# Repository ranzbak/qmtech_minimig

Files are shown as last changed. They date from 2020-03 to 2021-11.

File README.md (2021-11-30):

# Open Adaptive Amiga Retro System (Open AARS)

This PCB has been designed for my project in order to run the Minimig Amiga core on a board of my own design.
The core FPGA board I bought of Aliexpress, because soldering the very fine pitched BGA socket is too cumbersome.

More detailed documents regarding the I/O board can be found in the docs directory in this repository.

The board as is works, the features have been tested individually, but I'm still working on the Minimig port at this time.
Since I work on this in my spare time progress is not super fast, but progress is made.
For now I'm mostly learning and developing at the same time so a lot of stuff changes.
When the code base becomes more stable and usable I'll open the repository up.

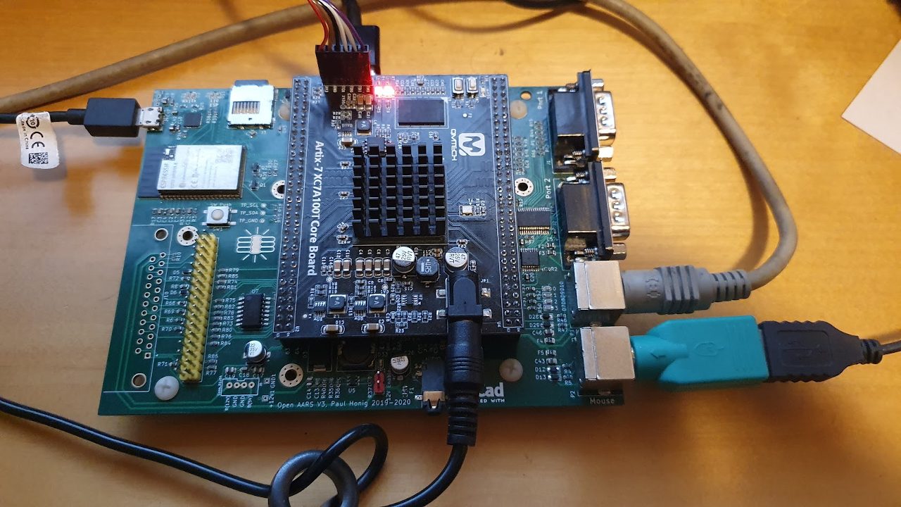
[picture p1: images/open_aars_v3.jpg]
Open AARS V3


[Firmware](https://github.com/ranzbak/MinimigAGA_TC64) for the Amiga works!

## Interfaces provided by this I/O board

- Atari/Amiga compatible Joystick ports
- PS/2 keyboard interface for mouse and keyboard
- Analog head phone jack via
- External floppy interface to connect Amiga floppy drives (Including 12V power pin)
- HDMI display connector that supports up to full HD video (1920x1080)
- 6 status LEDS
- Internal Amiga floppy drive connector
- External Amiga floppy drive connector (DIN-23)
- AS4C16M16SA-6TCN 32Mb SDRAM
- ADV7511 HDMI output PHY
- MAX9850 I2S Audio chip with built in amplifier
- SD-card interface
- RS-232 over USB to program and communicate with the Python shell

## Platforms that _could_ run with this IO board

- C64
- Amiga 1200/500(+) [https://github.com/ranzbak/MinimigAGA_TC64](https://github.com/ranzbak/MinimigAGA_TC64)
- Atari ST
- Other 80's and 90's machines?

Keep in mind I'm only planning on making an Amiga core for this board, but feel free to contribute other cores.

# The two boards that are compatible with this design are

## QM_XC7A100T_DDR3

### Specs

- On-Board FPGA: XC7A100T-2FGG676I;
- On-Board FPGA external crystal frequency: 50MHz;
- XC7A100T-2FGG676I has rich block RAM resource up to 4,860Kb;
- XC7A100T-2FGG676I has 101,440 logic cells;
- On-Board MT25QL128 SPI Flash,16M bytes for user configuration code;
- On-Board 256MB Micron DDR3，MT41K128M16JT-125:K;
- On-Board 3.3V power supply for FPGA by using MP2315 wide input range DC/DC;
- XC7A100T core board has two 64p, 2.54mm pitch headers for extending user IOs. All IOs are precisely designed with length matching;
- XC7A100T core board has 3 user switches;
- XC7A100T core board has 4 user LEDs;
- XC7A100T core board has JTAG interface, by using 6p, 2.54mm pitch header;
- XC7A100T core board PCB size is: 6.7cm x 8.4cm;
- Default power source for board is: 1A@5V DC, the DC header type: DC-050, 5.5mmx2.1mm;

### Github repo

[QM_XC7A100T_STARTER_KIT](https://github.com/ChinaQMTECH/QM_XC7A100T_STARTER_KIT)

### Listings at this time (2019-12-29)

- [Ebay QMTECH Xilinx FPGA Artix7 Artix-7 XC7A100T Core Board](https://www.ebay.com/itm/QMTECH-Xilinx-FPGA-Artix7-Artix-7-XC7A100T-Core-Board-/173922141347)
- [Aliexpress QMTECH Xilinx FPGA Artix7 Artix-7 XC7A100T DDR3 Core Board](vid=bcf629d3-8718-47b9-bad6-a31d7b1e778c&algo_expid=bcf629d3-8718-47b9-bad6-a31d7b1e778c-14&btsid=29203478-817f-4791-b6b6-1687369426ed&ws_ab_test=searchweb0_0,searchweb201602_3,searchweb201603_53)

## QM_XC7A35T_DDR3

### Specs

- On-Board FPGA: XC7A35T-1FTG256C;
- On-Board FPGA external crystal frequency: 50MHz;
- XC7A35T-1FTG256C has rich block RAM resource up to 1,800Kb;
- XC7A35T-1FTG256C has 33,280 logic cells;
- On-Board MT28QL128 SPI Flash, 16M bytes for user configuration code;
- On-Board 256MB Micron DDR3, MT41J128M16JT-125:K;
- On-Board 3.3V power supply for FPGA by using MP2315 wide input range DC/DC;
- XC7A35T development board has two 64p, 2.54mm pitch headers for extending user IOs. All IOs are precisely designed with length matching;
- XC7A35T development board has 2 user switches;
- XC7A35T development board has 3 user LEDs;
- XC7A35T development board has JTAG interface, by using 6p, 2.54mm pitch header;
- XC7A35T development board PCB size is: 6.7cm x 8.4cm;
- Default power source for board is: 1A@5V DC, the DC header type: DC-050, 5.5mmx2.1mm;

### Github repo

[QM_XC7A35T_DDR3](https://github.com/ChinaQMTECH/QM_XC7A35T_DDR3)

### Listings at this time (2019-12-29)

- [Ebay Xilinx FPGA Artix7 Artix-7 Core Board XC7A35T DDR3 256MB](https://www.ebay.com/itm/Xilinx-FPGA-Artix7-Artix-7-Core-Board-XC7A35T-DDR3-256MB/293211934785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)
- [Aliexpress QMTECH Xilinx FPGA Artix7 Artix-7 Core Board XC7A35T DDR3 256MB](https://www.aliexpress.com/item/1000006630084.html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,searchweb201602_3,searchweb201603_53)

** Make sure to ask the seller to ship the board without the female headers soldered on, for the Open AARS board male headers are needed. **

## Disclaimer

THE PROJECT IS PROVIDED "AS IS", WITHOUT WARRANTY OF ANY KIND, EXPRESS OR IMPLIED, INCLUDING BUT NOT LIMITED TO THE WARRANTIES OF MERCHANTABILITY, FITNESS FOR A PARTICULAR PURPOSE AND NONINFRINGEMENT. IN NO EVENT SHALL THE AUTHORS OR COPYRIGHT HOLDERS BE LIABLE FOR ANY CLAIM, DAMAGES OR OTHER LIABILITY, WHETHER IN AN ACTION OF CONTRACT, TORT OR OTHERWISE, ARISING FROM, OUT OF OR IN CONNECTION WITH THE PROJECT OR THE USE OR OTHER DEALINGS IN THE PROJECT.

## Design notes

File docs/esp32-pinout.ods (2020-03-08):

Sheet: Welcome
BADGE.TEAM
 | This spreadsheet contains the pinouts of the badges we support.
 | It is still a work in progress and may contain errors!
 | Version | 1.0.0
 | CHANGELOG
 | 1.0.0 | Initial version

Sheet: ESP32
GPIO | Power group | Bootstrap | Note | SHA2017 | HackerHotel 2019 | CampZone 2019 | Disobey 2019 | Disobey 2020 prototype 1 | Disobey 2020 prototype 2 | Espressif Wrover Kit | Odroid Go | TTGO LoRa | Fri3dcamp 2018 | OpenHardwareSummit 2018 | Troopers 2019 | Open aars
0 | VDD3P3_RTC | LOW=UART DL | Download / run | Flash / button | Flash / button | FLASH (/ PWM?) | Flash / button | Flash / button | Flash / button | Flash / button / LED 2 | Flash / button VOLUME | Flash / button | Flash / button | Flash | Flash | Flash / button
1 | VDD3P3_CPU | UART TX | Serial port TX | UART TX | UART TX | UART TX | UART TX | UART TX | UART TX | UART TX | UART TX | UART TX | UART TX | UART TX | UART TX | UART TX
2 | VDD3P3_RTC | Needs pull down for UART DL mode |  | SDCARD D0 | I2S DATA (OUT) | Not connected ?PWM? | Not connected | I2S1 DATA (OUT) | SDCARD D0 | SDCARD D0 / LED 3 | LED | LED | Display shift-register data | Power enable | SDCARD D0 | SDCARD D0
3 | VDD3P3_CPU | UART RX | Serial port RX | UART RX | UART RX | UART RX | UART RX | UART RX | UART RX | UART RX | UART RX | UART RX | UART RX | UART RX | UART RX | UART RX
4 | VDD3P3_RTC |  |  | EXTIO-3 | Vibration motor | I2C SDA | Not connected | WS2812 DATA | WS2812 DATA | SDCARD D1 / LED 1 | Unconnected / pinheader | I2C SDA | Display shift-register clk | EINK BUSY | I2C SDA | SDCARD D1
5 | VDD3P3_CPU |  |  | EINK MOSI | EINK MOSI | I2C CLK | Not connected | IR RX | IR TX | LCD backlight | LCD CS | LoRa SCK | SDCARD CS | EINK CS | I2C CLK
6 | VDD_SDIO |  | Not available | Internal flash CLK | Internal flash CLK | Internal flash CLK | Internal flash CLK | Internal flash CLK | Internal flash CLK | Internal flash CLK | Internal flash CLK | Internal flash CLK | Internal flash CLK | Internal flash CLK | Internal flash CLK | Internal flash CLK
7 | VDD_SDIO |  | Not available | Internal flash DO | Internal flash DO | Internal flash DO | Internal flash DO | Internal flash DO | Internal flash DO | Internal flash DO | Internal flash DO | Internal flash DO | Internal flash DO | Internal flash DO | Internal flash DO | Internal flash DO
8 | VDD_SDIO |  | Not available | Internal flash DI | Internal flash DI | Internal flash DI | Internal flash DI | Internal flash DI | Internal flash DI | Internal flash DI | Internal flash DI | Internal flash DI | Internal flash DI | Internal flash DI | Internal flash DI | Internal flash DI
9 | VDD_SDIO |  | Not available | Internal flash HOLD# | Internal flash HOLD# | Internal flash HOLD# | Internal flash HOLD# | Internal flash HOLD# | Internal flash HOLD# | Internal flash HOLD# | Internal flash HOLD# | Internal flash HOLD# | Internal flash HOLD# | Internal flash HOLD# | Internal flash HOLD# | Internal flash HOLD#
10 | VDD_SDIO |  | Not available | Internal flash WP# | Internal flash WP# | Internal flash WP# | Internal flash WP# | Internal flash WP# | Internal flash WP# | Internal flash WP# | Internal flash WP# | Internal flash WP# | Internal flash WP# | Internal flash WP# | Internal flash WP# | Internal flash WP#
11 | VDD_SDIO |  | Not available | Internal flash CS | Internal flash CS | Internal flash CS | Internal flash CS | Internal flash CS | Internal flash CS | Internal flash CS | Internal flash CS | Internal flash CS | Internal flash CS | Internal flash CS | Internal flash CS | Internal flash CS
12 | VDD3P3_RTC | VDD_SDIO LOW=3.3V HIGH=1.8V | MTDI | EXTIO-4 | IR RX | Not connected (10k to GND) | EXTIO-1 | Buzzer | Buzzer | SDCARD D2 / MTDI | Unconnected / pinheader | Unconnected / pinheader | UART 1 TX | T5 | Not connected | SDCARD D2
13 | VDD3P3_RTC |  |  | SDCARD D3 | I2S CLK | HUB75 R0 | Not connected | I2S1 CLK | I2S1 CLK | SDCARD D3 / MTCK | Button MENU | Unconnected / pinheader | Display shift-register OE | T4 | EINK BUSY | SDCARD D3
14 | VDD3P3_RTC |  |  | SDCARD CLK | IR TX | HUB75 B0 | EXTIO-0 | IR TX | SDCARD CLK | SDCARD CLK / MTMS | LCD backlight | LoRa RESET | UART 2 RX | T6 | SDCARD CLK | SDCARD CLK
15 | VDD3P3_RTC | LOW=BL SILENT, HIGH=BL DEBUG | MTDO | SDCARD CMD | I2S L/R | HUB75 G0 | Not connected | I2S1 L/R | SDCARD CMD | SDCARD CMD / MTDO | Unconnected / pinheader | I2C CLK | Display shift-register latch | SDCARD CS | SDCARD CMD | SDCARD CMD
16 | VDD_SDIO |  |  | EXTIO-1 | Internal SRAM CS | HUB75 A | Not connected | Internal SRAM CS | Internal SRAM CS | Internal SRAM CS | Internal SRAM CS | Display reset | UART 2 RX | EINK RESET | Internal SRAM CS | Internal SRAM CS
17 | VDD_SDIO |  |  | EXTIO-2 | Internal SRAM CLK | HUB75 B | Not connected | Internal SRAM CLK | Internal SRAM CLK | Internal SRAM CLK | Internal SRAM CLK | Unconnected / pinheader | UART 2 TX | Not connected | Internal SRAM CLK | Internal SRAM CLK
18 | VDD3P3_CPU |  |  | EINK SCK | EINK SCK | HUB75 C | IR RX | IR RX PWR | I2S1 DATA (OUT) | LCD RESET | LCD CLK | LoRa CS | SDCARD CLK | EINK SCK | EINK SCK | VSPI_FPGA_CLK
19 | VDD3P3_CPU |  |  | EINK CS | EINK CS | HUB75 LAT | IR TX | I2C interrupt (MPR121) | Not connected | LCD CLK | LCD MISO | LoRa MOSI | SDCARD DO | MISO | LED | VSPI_FPGA_MISO
21 | VDD3P3_CPU |  |  | EINK D/C | EINK D/C | HUB75 CLK | IR RX PWR | SSD1306 RESET | I2S1 L/R | LCD D/C | LCD D/C | Unconnected / pinheader | I2C SDA | I2C SDA | I2C interrupt (Accelerometer) | LED0
22 | VDD3P3_CPU |  |  | EINK BUSY | EINK BUSY | HUB75 OE | I2C SCL | I2C SCL | I2C SCL | LCD CS | SDCARD CS | Unconnected / pinheader | I2C CLK | I2C CLK | WS2812 DATA | LED1
23 | VDD3P3_CPU |  |  | EINK RESET | EINK RESET | CHARGE ENABLE | I2C SDA | I2C SDA | I2C SDA | LCD MOSI | LCD MOSI | Unconnected / pinheader | SDCARD DI | EINK MOSI | EINK MOSI | VSPI_FPGA_MOSI
25 | VDD3P3_RTC |  | DAC1 | I2C interrupt (MPR121) | I2C interrupt (MPR121) | Not connected | I2C interrupt (SAMD) | I2S0 CLK | I2S0 CLK | LCD MISO | DAC (check schematic!) | Unconnected / pinheader | PWM 1 | EINK D/C | EINK CS | FPGA_INT
26 | VDD3P3_RTC |  | DAC2 | I2C SDA | I2C SDA | Button up | EXTIO-2 | EXTIO-0 | EXTIO-0 | Unconnected / pinheader | DAC (check schematic!) | LoRa interrupt | PWM 2 | “LED_BAR_DOUT” but seems NC | Grove signal pin 1 | ADV_I2C SDA
27 | VDD3P3_RTC |  |  | I2C SCL | I2C SCL | Button down | EXTIO-3 | EXTIO-1 | EXTIO-1 | Unconnected / pinheader | Button SELECT | LoRa MOSI | PWM 3 | T7 | EINK D/C | ADV_I2C SCL
32 | VDD3P3_RTC |  |  | WS2812 DATA | WS2812 DATA | Button left | Not connected | Badge type detection | Badge type detection | 32kHz crystal P | Button A | Unconnected / pinheader | h | T9 | 32kHz crystal P | SDCARD power EN (active low)
33 | VDD3P3_RTC |  |  | EXTIO-0 | Not connected | Button right | Not connected | VUSB SENS | IR RX | 32kHz crystal N | Button B | Unconnected / pinheader | Buzzer | T8 | 32kHz crystal N | VSPI_FPGA_CS
34 | VDD3P3_RTC |  | Input only | VUSB SENS | VUSB SENS | VUSB SENS | Not connected | VBAT SENS | I2C interrupt (MPR121) | Unconnected / pinheader | JOY LEFT/RIGHT (analog) | Unconnected / pinheader | I2C interrupt (Accelerometer 1) | I2C interrupt (Accelerometer) | I2C interrupt (PCA9555 / Key 1) | SD_CARD_SW
35 | VDD3P3_RTC |  | Input only | VBAT SENS | VBAT SENS | VBAT SENS | Not connected | I2S0 DATA (IN) | I2S0 DATA (IN) | Unconnected / pinheader | JOY UP/DOWN (analog) | Unconnected / pinheader | I2C interrupt (Accelerometer 2) | VBAT SENS | I2C interrupt (PCA9555 / Key 0) | ADV_INT
36 | VDD3P3_RTC |  | Input only (VP) | Not connected | Not connected | Button A | Not connected | Not connected | VUSB SENS | Unconnected / pinheader | VBAT SENS | Unconnected / pinheader | Button 0 | Not connected | Grove signal pin 0 | Free (Wakeup source, input only)
39 | VDD3P3_RTC |  | Input only (VN) | Not connected | Not connected | Button B | Not connected | Not connected | VBAT SENS | Unconnected / pinheader | Button START | Unconnected / pinheader | Button 1 | Not connected | I2C interrupt (PCA9539A / Button) | Free (Wakeup source, input only)
Note | This row contains notes about each design |  |  | SDCARD D3 seems useless | Audio output is wired wrong | I2C pull-ups have wrong | SAMD handles most I/O | Prototype, do NOT copy | Prototype, do NOT copy | Development board | SD card shares EINK SPI (See notes!) | LoRa radio is not yet | SD card can only be used in SPI mode | SD card shares EINK SPI (See notes!) | Not yet supported by badge.team
 |  |  |  |  | needs software workaround | value, please swap if you |  | (Contains mistakes!) |  | (Some features share pins!) | (Shitty design, do not copy!) | supported |  | Touch buttons are not yet supported | firmware
 |  |  |  |  |  | plan on using I2C
 |  | Design hints
 |  | - If you want to be able to wake-up the ESP32 from deep-sleep using a pin make sure that the pin you use is in the VDD3P3_RTC power domain (Disobey 2020 prototype 1 got this wrong…)
 |  | - The SPI bus used by the internal flash can only be used for the internal flash
 |  | - Make sure you strap the bootstrap pins correctly! If you want to you can burn an e-fuse to fix the voltage set by GPIO 12. We had to do this for the hackerhotel 2019 badge
 |  | - The SPI/SD bus used by an SD card can not be shared with other devices, this is a (software) limitation of the ESP-IDF SDK which we do not (yet) have a workaround for
 |  | - To use the SD card in SD mode make sure that you use the right pins to do so, you need the exact pins used on the SHA2017 badge to utilize the SDIO hardware of the ESP32. We wired it up in 1-wire mode, you can also do 4-wire mode for more speed if needed.

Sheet: MPR121
ELE | SHA2017 | HackerHotel 2019 | Disobey 2020 prototype 1
0 | Touch button A | Touch button SELECT | Touch button UP
1 | Touch button B | Touch button START | Touch button DOWN
2 | Touch button START | Touch button A | Touch button LEFT
3 | Touch button SELECT | Touch button UP / RIGHT | Touch button RIGHT
4 | Touch button DOWN | Touch button LEFT / UP | Touch button A
5 | Touch button RIGHT | Touch button DOWN / LEFT | Touch button B
6 | Touch button UP | Touch button RIGHT / DOWN | Touch button SELECT
7 | Touch button LEFT | Touch button B | Touch button START
8 | Vibration motor | Not connected | LED 1
9 | Charging status | Charging status | LED 2
10 | WS2812 / SD power enable | WS2812 power enable | WS2812 power enable
11 | SD card detect | Not connected | SSD1306 power disable
Note | Sd card detect does not |  | Interrupt not wired to pin
 | work |  | capable of deepsleep wakeup
 | COLORS
 | Touch input
 | Digital input
 | Digital output
 | PWM output
 | Not connected

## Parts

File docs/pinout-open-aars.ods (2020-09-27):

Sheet: Sheet1
U71 | GND | Power input | Line | Right | 1,270 mm | 1,270 mm | 5,080 mm | -103,810 mm | 38,176 mm
U72 | GND | Power input | Line | Left | 1,270 mm | 1,270 mm | 5,080 mm | -62,840 mm | 38,176 mm
U73 | 3V3 | Power output | Line | Right | 1,270 mm | 1,270 mm | 5,080 mm | -103,810 mm | 35,636 mm | Space | 2540
U74 | 3V3 | Power output | Line | Left | 1,270 mm | 1,270 mm | 5,080 mm | -62,840 mm | 35,636 mm
U75 | GND | Power input | Line | Right | 1,270 mm | 1,270 mm | 5,080 mm | -103,810 mm | 33,096 mm
U76 | GND | Power input | Line | Left | 1,270 mm | 1,270 mm | 5,080 mm | -62,840 mm | 33,096 mm
U77 | BANK14_M12 | Unspecified | Line | Right | 1,270 mm | 1,270 mm | 5,080 mm | -103,810 mm | 30,556 mm
U78 | BANK14_N13 | Unspecified | Line | Left | 1,270 mm | 1,270 mm | 5,080 mm | -62,840 mm | 30,556 mm
U79 | BANK14_M14 | Unspecified | Line | Right | 1,270 mm | 1,270 mm | 5,080 mm | -103,810 mm | 28,016 mm
U710 | BANK14_N16 | Unspecified | Line | Left | 1,270 mm | 1,270 mm | 5,080 mm | -62,840 mm | 28,016 mm
U711 | BANK14_P15 | Unspecified | Line | Right | 1,270 mm | 1,270 mm | 5,080 mm | -103,810 mm | 25,476 mm
U712 | BANK14_P16 | Unspecified | Line | Left | 1,270 mm | 1,270 mm | 5,080 mm | -62,840 mm | 25,476 mm
U713 | BANK14_R15 | Unspecified | Line | Right | 1,270 mm | 1,270 mm | 5,080 mm | -103,810 mm | 22,936 mm
U714 | BANK14_R16 | Unspecified | Line | Left | 1,270 mm | 1,270 mm | 5,080 mm | -62,840 mm | 22,936 mm
U715 | BANK14_T14 | Unspecified | Line | Right | 1,270 mm | 1,270 mm | 5,080 mm | -103,810 mm | 20,396 mm
U716 | BANK14_T15 | Unspecified | Line | Left | 1,270 mm | 1,270 mm | 5,080 mm | -62,840 mm | 20,396 mm
U717 | BANK14_P13 | Unspecified | Line | Right | 1,270 mm | 1,270 mm | 5,080 mm | -103,810 mm | 17,856 mm
U718 | BANK14_P14 | Unspecified | Line | Left | 1,270 mm | 1,270 mm | 5,080 mm | -62,840 mm | 17,856 mm
U719 | BANK14_T13 | Unspecified | Line | Right | 1,270 mm | 1,270 mm | 5,080 mm | -103,810 mm | 15,316 mm
U720 | BANK14_R13 | Unspecified | Line | Left | 1,270 mm | 1,270 mm | 5,080 mm | -62,840 mm | 15,316 mm
U721 | BANK14_T12 | Unspecified | Line | Right | 1,270 mm | 1,270 mm | 5,080 mm | -103,810 mm | 12,776 mm
U722 | BANK14_R12 | Unspecified | Line | Left | 1,270 mm | 1,270 mm | 5,080 mm | -62,840 mm | 12,776 mm
U723 | BANK14_L13 | Unspecified | Line | Right | 1,270 mm | 1,270 mm | 5,080 mm | -103,810 mm | 10,236 mm
U724 | BANK14_N12 | Unspecified | Line | Left | 1,270 mm | 1,270 mm | 5,080 mm | -62,840 mm | 10,236 mm
U725 | BANK14_K12 | Unspecified | Line | Right | 1,270 mm | 1,270 mm | 5,080 mm | -103,810 mm | 7,696 mm
U726 | BANK14_K13 | Unspecified | Line | Left | 1,270 mm | 1,270 mm | 5,080 mm | -62,840 mm | 7,696 mm
U727 | BANK14_P10 | Unspecified | Line | Right | 1,270 mm | 1,270 mm | 5,080 mm | -103,810 mm | 5,156 mm
U728 | BANK14_P11 | Unspecified | Line | Left | 1,270 mm | 1,270 mm | 5,080 mm | -62,840 mm | 5,156 mm
U729 | BANK14_N9 | Unspecified | Line | Right | 1,270 mm | 1,270 mm | 5,080 mm | -103,810 mm | 2,616 mm
U730 | BANK14_P9 | Unspecified | Line | Left | 1,270 mm | 1,270 mm | 5,080 mm | -62,840 mm | 2,616 mm
U731 | BANK14_T10 | Unspecified | Line | Right | 1,270 mm | 1,270 mm | 5,080 mm | -103,810 mm | 0,076 mm
U732 | BANK14_R11 | Unspecified | Line | Left | 1,270 mm | 1,270 mm | 5,080 mm | -62,840 mm | 0,076 mm
U733 | BANK14_T9 | Unspecified | Line | Right | 1,270 mm | 1,270 mm | 5,080 mm | -103,810 mm | -2,464 mm
U734 | BANK14_R10 | Unspecified | Line | Left | 1,270 mm | 1,270 mm | 5,080 mm | -62,840 mm | -2,464 mm
U735 | BANK14_T8 | Unspecified | Line | Right | 1,270 mm | 1,270 mm | 5,080 mm | -103,810 mm | -5,004 mm
U736 | BANK14_R8 | Unspecified | Line | Left | 1,270 mm | 1,270 mm | 5,080 mm | -62,840 mm | -5,004 mm
U737 | BANK14_T7 | Unspecified | Line | Right | 1,270 mm | 1,270 mm | 5,080 mm | -103,810 mm | -7,544 mm
U738 | BANK14_R7 | Unspecified | Line | Left | 1,270 mm | 1,270 mm | 5,080 mm | -62,840 mm | -7,544 mm
U739 | BANK14_T5 | Unspecified | Line | Right | 1,270 mm | 1,270 mm | 5,080 mm | -103,810 mm | -10,084 mm
U740 | BANK14_R6 | Unspecified | Line | Left | 1,270 mm | 1,270 mm | 5,080 mm | -62,840 mm | -10,084 mm
U741 | BANK14_P6 | Unspecified | Line | Right | 1,270 mm | 1,270 mm | 5,080 mm | -103,810 mm | -12,624 mm
U742 | BANK14_R5 | Unspecified | Line | Left | 1,270 mm | 1,270 mm | 5,080 mm | -62,840 mm | -12,624 mm
U743 | BANK14_N6 | Unspecified | Line | Right | 1,270 mm | 1,270 mm | 5,080 mm | -103,810 mm | -15,164 mm
U744 | BANK14_M6 | Unspecified | Line | Left | 1,270 mm | 1,270 mm | 5,080 mm | -62,840 mm | -15,164 mm
U745 | BANK34_L5 | Unspecified | Line | Right | 1,270 mm | 1,270 mm | 5,080 mm | -103,810 mm | -17,704 mm
U746 | BANK34_P5 | Unspecified | Line | Left | 1,270 mm | 1,270 mm | 5,080 mm | -62,840 mm | -17,704 mm
U747 | BANK34_T4 | Unspecified | Line | Right | 1,270 mm | 1,270 mm | 5,080 mm | -103,810 mm | -20,244 mm
U748 | BANK34_T3 | Unspecified | Line | Left | 1,270 mm | 1,270 mm | 5,080 mm | -62,840 mm | -20,244 mm
U749 | BANK34_R3 | Unspecified | Line | Right | 1,270 mm | 1,270 mm | 5,080 mm | -103,810 mm | -22,784 mm
U750 | BANK34_T2 | Unspecified | Line | Left | 1,270 mm | 1,270 mm | 5,080 mm | -62,840 mm | -22,784 mm
U751 | BANK34_R2 | Unspecified | Line | Right | 1,270 mm | 1,270 mm | 5,080 mm | -103,810 mm | -25,324 mm
U752 | BANK34_R1 | Unspecified | Line | Left | 1,270 mm | 1,270 mm | 5,080 mm | -62,840 mm | -25,324 mm
U753 | BANK34_M5 | Unspecified | Line | Right | 1,270 mm | 1,270 mm | 5,080 mm | -103,810 mm | -27,864 mm
U754 | BANK34_N4 | Unspecified | Line | Left | 1,270 mm | 1,270 mm | 5,080 mm | -62,840 mm | -27,864 mm
U755 | BANK34_P4 | Unspecified | Line | Right | 1,270 mm | 1,270 mm | 5,080 mm | -103,810 mm | -30,404 mm
U756 | BANK34_P3 | Unspecified | Line | Left | 1,270 mm | 1,270 mm | 5,080 mm | -62,840 mm | -30,404 mm
U757 | BANK34_N1 | Unspecified | Line | Right | 1,270 mm | 1,270 mm | 5,080 mm | -103,810 mm | -32,944 mm
U758 | BANK34_P1 | Unspecified | Line | Left | 1,270 mm | 1,270 mm | 5,080 mm | -62,840 mm | -32,944 mm
U759 | BANK34_M2 | Power input | Line | Right | 1,270 mm | 1,270 mm | 5,080 mm | -103,810 mm | -35,484 mm
U760 | BANK34_M1 | Power input | Line | Left | 1,270 mm | 1,270 mm | 5,080 mm | -62,840 mm | -35,484 mm
U761 | 3V3 | Power output | Line | Right | 1,270 mm | 1,270 mm | 5,080 mm | -103,810 mm | -38,024 mm
U762 | 3V3 | Power output | Line | Left | 1,270 mm | 1,270 mm | 5,080 mm | -62,840 mm | -38,024 mm
U763 | VIN | Power output | Line | Right | 1,270 mm | 1,270 mm | 5,080 mm | -103,810 mm | -40,564 mm
U764 | VIN | Power output | Line | Left | 1,270 mm | 1,270 mm | 5,080 mm | -62,840 mm | -40,564 mm
U81 | GND | Power input | Line | Right | 1,270 mm | 1,270 mm | 5,080 mm | 61,290 mm | 38,176 mm
U82 | GND | Power input | Line | Left | 1,270 mm | 1,270 mm | 5,080 mm | 102,260 mm | 38,176 mm
U83 | 3V3 | Power output | Line | Right | 1,270 mm | 1,270 mm | 5,080 mm | 61,290 mm | 35,636 mm
U84 | 3V3 | Power output | Line | Left | 1,270 mm | 1,270 mm | 5,080 mm | 102,260 mm | 35,636 mm
U85 | GND | Power input | Line | Right | 1,270 mm | 1,270 mm | 5,080 mm | 61,290 mm | 33,096 mm
U86 | GND | Power input | Line | Left | 1,270 mm | 1,270 mm | 5,080 mm | 102,260 mm | 33,096 mm
U87 | BANK35_B7 | Unspecified | Line | Right | 1,270 mm | 1,270 mm | 5,080 mm | 61,290 mm | 30,556 mm
U88 | BANK35_A7 | Unspecified | Line | Left | 1,270 mm | 1,270 mm | 5,080 mm | 102,260 mm | 30,556 mm
U89 | GND | Unspecified | Line | Right | 1,270 mm | 1,270 mm | 5,080 mm | 61,290 mm | 28,016 mm
U810 | GND | Unspecified | Line | Left | 1,270 mm | 1,270 mm | 5,080 mm | 102,260 mm | 28,016 mm
U811 | BANK35_E6 | Unspecified | Line | Right | 1,270 mm | 1,270 mm | 5,080 mm | 61,290 mm | 25,476 mm
U812 | BANK35_K5 | Unspecified | Line | Left | 1,270 mm | 1,270 mm | 5,080 mm | 102,260 mm | 25,476 mm
U813 | BANK35_J5 | Unspecified | Line | Right | 1,270 mm | 1,270 mm | 5,080 mm | 61,290 mm | 22,936 mm
U814 | BANK35_J4 | Unspecified | Line | Left | 1,270 mm | 1,270 mm | 5,080 mm | 102,260 mm | 22,936 mm
U815 | BANK35_G5 | Unspecified | Line | Right | 1,270 mm | 1,270 mm | 5,080 mm | 61,290 mm | 20,396 mm
U816 | BANK35_G4 | Unspecified | Line | Left | 1,270 mm | 1,270 mm | 5,080 mm | 102,260 mm | 20,396 mm
U817 | BANK35_C7 | Unspecified | Line | Right | 1,270 mm | 1,270 mm | 5,080 mm | 61,290 mm | 17,856 mm
U818 | BANK35_C6 | Unspecified | Line | Left | 1,270 mm | 1,270 mm | 5,080 mm | 102,260 mm | 17,856 mm
U819 | BANK35_D6 | Unspecified | Line | Right | 1,270 mm | 1,270 mm | 5,080 mm | 61,290 mm | 15,316 mm
U820 | BANK35_D5 | Unspecified | Line | Left | 1,270 mm | 1,270 mm | 5,080 mm | 102,260 mm | 15,316 mm
U821 | BANK35_A5 | Unspecified | Line | Right | 1,270 mm | 1,270 mm | 5,080 mm | 61,290 mm | 12,776 mm
U822 | BANK35_A4 | Unspecified | Line | Left | 1,270 mm | 1,270 mm | 5,080 mm | 102,260 mm | 12,776 mm
U823 | BANK35_B4 | Unspecified | Line | Right | 1,270 mm | 1,270 mm | 5,080 mm | 61,290 mm | 10,236 mm
U824 | BANK35_A3 | Unspecified | Line | Left | 1,270 mm | 1,270 mm | 5,080 mm | 102,260 mm | 10,236 mm
U825 | BANK35_D4 | Unspecified | Line | Right | 1,270 mm | 1,270 mm | 5,080 mm | 61,290 mm | 7,696 mm
U826 | BANK35_C4 | Unspecified | Line | Left | 1,270 mm | 1,270 mm | 5,080 mm | 102,260 mm | 7,696 mm
U827 | BANK35_C3 | Unspecified | Line | Right | 1,270 mm | 1,270 mm | 5,080 mm | 61,290 mm | 5,156 mm
U828 | BANK35_C2 | Unspecified | Line | Left | 1,270 mm | 1,270 mm | 5,080 mm | 102,260 mm | 5,156 mm
U829 | BANK35_B2 | Unspecified | Line | Right | 1,270 mm | 1,270 mm | 5,080 mm | 61,290 mm | 2,616 mm
U830 | BANK35_A2 | Unspecified | Line | Left | 1,270 mm | 1,270 mm | 5,080 mm | 102,260 mm | 2,616 mm
U831 | BANK35_C1 | Unspecified | Line | Right | 1,270 mm | 1,270 mm | 5,080 mm | 61,290 mm | 0,076 mm
U832 | BANK35_B1 | Unspecified | Line | Left | 1,270 mm | 1,270 mm | 5,080 mm | 102,260 mm | 0,076 mm
U833 | BANK35_E2 | Unspecified | Line | Right | 1,270 mm | 1,270 mm | 5,080 mm | 61,290 mm | -2,464 mm
U834 | BANK35_D1 | Unspecified | Line | Left | 1,270 mm | 1,270 mm | 5,080 mm | 102,260 mm | -2,464 mm
U835 | BANK35_E3 | Unspecified | Line | Right | 1,270 mm | 1,270 mm | 5,080 mm | 61,290 mm | -5,004 mm
U836 | BANK35_D3 | Unspecified | Line | Left | 1,270 mm | 1,270 mm | 5,080 mm | 102,260 mm | -5,004 mm
U837 | BANK35_F5 | Unspecified | Line | Right | 1,270 mm | 1,270 mm | 5,080 mm | 61,290 mm | -7,544 mm
U838 | BANK35_E5 | Unspecified | Line | Left | 1,270 mm | 1,270 mm | 5,080 mm | 102,260 mm | -7,544 mm
U839 | BANK35_F2 | Unspecified | Line | Right | 1,270 mm | 1,270 mm | 5,080 mm | 61,290 mm | -10,084 mm
U840 | BANK35_E1 | Unspecified | Line | Left | 1,270 mm | 1,270 mm | 5,080 mm | 102,260 mm | -10,084 mm
U841 | BANK35_F4 | Unspecified | Line | Right | 1,270 mm | 1,270 mm | 5,080 mm | 61,290 mm | -12,624 mm
U842 | BANK35_F3 | Unspecified | Line | Left | 1,270 mm | 1,270 mm | 5,080 mm | 102,260 mm | -12,624 mm
U843 | BANK35_G2 | Unspecified | Line | Right | 1,270 mm | 1,270 mm | 5,080 mm | 61,290 mm | -15,164 mm
U844 | BANK35_G1 | Unspecified | Line | Left | 1,270 mm | 1,270 mm | 5,080 mm | 102,260 mm | -15,164 mm
U845 | BANK35_H2 | Unspecified | Line | Right | 1,270 mm | 1,270 mm | 5,080 mm | 61,290 mm | -17,704 mm
U846 | BANK35_H1 | Unspecified | Line | Left | 1,270 mm | 1,270 mm | 5,080 mm | 102,260 mm | -17,704 mm
U847 | BANK35_K1 | Unspecified | Line | Right | 1,270 mm | 1,270 mm | 5,080 mm | 61,290 mm | -20,244 mm
U848 | BANK35_J1 | Unspecified | Line | Left | 1,270 mm | 1,270 mm | 5,080 mm | 102,260 mm | -20,244 mm
U849 | BANK35_L3 | Unspecified | Line | Right | 1,270 mm | 1,270 mm | 5,080 mm | 61,290 mm | -22,784 mm
U850 | BANK35_L2 | Unspecified | Line | Left | 1,270 mm | 1,270 mm | 5,080 mm | 102,260 mm | -22,784 mm
U851 | BANK35_H5 | Unspecified | Line | Right | 1,270 mm | 1,270 mm | 5,080 mm | 61,290 mm | -25,324 mm
U852 | BANK35_H4 | Unspecified | Line | Left | 1,270 mm | 1,270 mm | 5,080 mm | 102,260 mm | -25,324 mm
U853 | BANK35_J3 | Unspecified | Line | Right | 1,270 mm | 1,270 mm | 5,080 mm | 61,290 mm | -27,864 mm
U854 | BANK35_H3 | Unspecified | Line | Left | 1,270 mm | 1,270 mm | 5,080 mm | 102,260 mm | -27,864 mm
U855 | BANK35_K3 | Unspecified | Line | Right | 1,270 mm | 1,270 mm | 5,080 mm | 61,290 mm | -30,404 mm
U856 | BANK35_K2 | Unspecified | Line | Left | 1,270 mm | 1,270 mm | 5,080 mm | 102,260 mm | -30,404 mm
U857 | BANK35_L4 | Unspecified | Line | Right | 1,270 mm | 1,270 mm | 5,080 mm | 61,290 mm | -32,944 mm
U858 | BANK35_M4 | Unspecified | Line | Left | 1,270 mm | 1,270 mm | 5,080 mm | 102,260 mm | -32,944 mm
U859 | BANK35_N3 | Unspecified | Line | Right | 1,270 mm | 1,270 mm | 5,080 mm | 61,290 mm | -35,484 mm
U860 | BANK35_N2 | Unspecified | Line | Left | 1,270 mm | 1,270 mm | 5,080 mm | 102,260 mm | -35,484 mm
U861 | 3V3 | Unspecified | Line | Right | 1,270 mm | 1,270 mm | 5,080 mm | 61,290 mm | -38,024 mm
U862 | 3V3 | Unspecified | Line | Left | 1,270 mm | 1,270 mm | 5,080 mm | 102,260 mm | -38,024 mm
U863 | VIN | Unspecified | Line | Right | 1,270 mm | 1,270 mm | 5,080 mm | 61,290 mm | -40,564 mm
U864 | VIN | Unspecified | Line | Left | 1,270 mm | 1,270 mm | 5,080 mm | 102,260 mm | -40,564 mm

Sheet: AARS v2
a7t34 | Pin a7t | Bank | a7t100 | Func a7t100 | Bank | Function | Direction | Orientation | 35T caps | 100T caps
Left Connector
U71 |  |  | U41 |  |  | GND | Power input | Left
U72 |  |  | U42 |  |  | GND | Power input | Right
U73 |  |  | U43 |  |  | 3V3 | Power output | Left
U74 |  |  | U44 |  |  | 3V3 | Power output | Right
U75 |  |  | U45 |  |  | GND | Bidirectional | Left
U76 |  |  | U46 |  |  | GND | Unspecified | Right
U77 | M12 | 14 | U47 | D26 | IO | ADV_VSYNC | Power input | Left
U78 | N13 | 14 | U48 | E26 | IO | JS1_5 | Output | Right
U79 | N14 | 14 | U49 | D25 | IO | ADV_HSYNC | Power input | Left
U710 | N16 | 14 | U410 | E25 | IO | JS1_9 | Output | Right
U711 | P15 | 14 | U411 | G26 | IO | ADV_DE | Power input | Left
U712 | P16 | 14 | U412 | H26 | IO | JS1_4 | Output | Right
U713 | R15 | 14 | U413 | E23 | IO | ADV_B_0 | Output | Left
U714 | R16 | 14 | U414 | F23 | IO | JS1_3 | Output | Right
U715 | T14 | 14 | U415 | F22 | IO | ADV_B_1 | Input | Left
U716 | T15 | 14 | U416 | G22 | IO | JS1_7 | Output | Right
U717 | P13 | 14 | U417 | J26 | IO | ADV_B_2 | Output | Left
U718 | P14 | 14 | U418 | J25 | IO | JS1_2 | Output | Right
U719 | T13 | 14 | U419 | G21 | IO | ADV_B_3 | Output | Left |  | SRCC_N
U720 | R13 | 14 | U420 | G20 | IO | JS1_6 | Output | Right |  | SRCC_P
U721 | T12 | 14 | U421 | H22 | IO | ADV_B_4 | Power input | Left
U722 | R12 | 14 | U422 | H21 | IO | JS1_1 | Output | Right |  | MRCC_P
U723 | L13 | 14 | U423 | J21 | IO | ADV_B_5 | Power input | Left |  | MRCC_N
U724 | N12 | 14 | U424 | K21 | IO | NC | Output | Right |  | MRCC_P
U725 | K12 | 14 | U425 | K26 | IO | ADV_B_6 | Power input | Left |  | MRCC_N
U726 | K13 | 14 | U426 | K25 | IO | NC | Output | Right
U727 | P10 | 14 | U427 | K23 | IO | ADV_B_7 | Power input | Left
U728 | P11 | 14 | U428 | K22 | IO | NC | Output | Right |  | SRCC_P
U729 | N9 | 14 | U429 | M26 | IO | ADV_G_0 | Power input | Left
U730 | P9 | 14 | U430 | N26 | IO | JS2_5 | Output | Right
U731 | T10 | 14 | U431 | L23 | IO | ADV_CLK | Power input | Left |  | SRCC_N
U732 | R11 | 14 | U432 | L22 | IO | JS2_9 | Output | Right
U733 | T9 | 14 | U433 | P26 | IO | ADV_G_1 | Power input | Left
U734 | R10 | 14 | U434 | R26 | IO | JS2_4 | Output | Right
U735 | T8 | 14 | U435 | M25 | IO | ADV_I2S0 | Power input | Left
U736 | R8 | 14 | U436 | M24 | IO | JS2_3 | Output | Right
U737 | T7 | 14 | U437 | N22 | IO | ADV_I2S1 | Power input | Left
U738 | R7 | 14 | U438 | N21 | IO | JS2_7 | Bidirectional | Right
U739 | T5 | 14 | U439 | P24 | IO | NC | Power input | Left
U740 | R6 | 14 | U440 | P23 | IO | JS2_2 | Output | Right
U741 | P6 | 14 | U441 | P25 | IO | NC | Power input | Left
U742 | R5 | 14 | U442 | R25 | IO | JS2_6 | Output | Right
U743 | N6 | 14 | U443 | T25 | IO | ADV_SCLK | Output | Left
U744 | M6 | 14 | U444 | T24 | IO | JS2_1 | Output | Right
U745 | L5 | 34 | U445 | V21 | IO | ADV_LRCLK | Output | Left |  | MRCC_N
U746 | P5 | 34 | U446 | U21 | IO | LED0 | Output | Right |  | MRCC_P
U747 | T4 | 34 | U447 | W23 | IO | PS2_CLK2 | Output | Left
U748 | T3 | 34 | U448 | V23 | IO | LED1 | Output | Right
U749 | R3 | 34 | U449 | Y23 | IO | PS2_DAT2 | Output | Left |  | SRCC_N
U750 | T2 | 34 | U450 | Y22 | IO | LED2 | Output | Right |  | SRCC_P
U751 | R2 | 34 | U451 | AA25 | IO | MAX_I2S0 | Output | Left
U752 | R1 | 34 | U452 | Y25 | IO | LED3 | Output | Right
U753 | M5 | 34 | U453 | Y21 | IO | LED5 | Output | Left |  | SRCC_N
U754 | N4 | 34 | U454 | W21 | IO | LED4 | Output | Right |  | SRCC_P
U755 | P4 | 34 | U455 | AC24 | IO | LED7 | Output | Left
U756 | P3 | 34 | U456 | AB24 | IO | LED6 | Output | Right
U757 | N1 | 34 | U457 | Y26 | IO | MAX_SCLK | Power input | Left
U758 | P1 | 34 | U458 | W25 | IO | PS2_CLK1 | Power input | Right
U759 | M2 | 34 | U459 | AC26 | IO | MAX_LRCLK | Power input | Left
U760 | M1 | 34 | U460 | AB26 | IO | PS2_DAT1 | Power input | Right
U761 |  |  | U461 |  |  | GND | Power input | Left
U762 |  |  | U462 |  |  | 3V3 | Power input | Right
U763 |  |  | U463 |  |  | VIN5V | Power input | Left
U764 |  |  | U464 |  |  | VIN5V | Power input | Right
Right connector
U81 |  |  | U21 |  |  | GND | GND | Left
U82 |  |  | U22 |  |  | GND | GND | Right
U83 |  |  | U23 |  |  | 3V3 | Power input | Left
U84 |  |  | U24 |  |  | 3V3 | Power input | Right
U85 |  |  | U25 |  |  | GND | GND | Left
U86 |  |  | U26 |  |  | GND | GND | Right
U87 | B7 | 35 | U27 | A5 | 15 | NC | Output | Left
U88 | A7 | 35 | U28 | B5 | 15 | ADV_R_7 | Input | Right
U89 | B6 | 35 | U29 | A4 | 15 | NC | Output | Left
U810 | B5 | 35 | U210 | B4 | 15 | ADV_R_6 | Input | Right
U811 | E6 | 35 | U211 | A2 | 15 | NC | Output | Left
U812 | K5 | 35 | U212 | A3 | 15 | ADV_R_5 | Input | Right
U813 | J5 | 35 | U213 | C2 | 15 | NC | Output | Left
U814 | J4 | 35 | U214 | B2_VREF | 15 | ADV_R_4 | Input | Right
U815 | G5 | 35 | U215 | D4 | 15 | NC | Output | Left |  | SRCC_P
U816 | G4 | 35 | U216 | C4 | 15 | ADV_R_3 | Input | Right |  | SRCC_N
U817 | C7 | 35 | U217 | D5 | 15 | ESP_VSPI_CLK | Output | Left |  | MRCC_N
U818 | C6 | 35 | U218 | E5 | 15 | ADV_R_2 | Input | Right
U819 | D6 | 35 | U219 | B1 | 15 | ESP_VSPI_MISO | Output | Left
U820 | D5 | 35 | U220 | C1 | 15 | ADV_R_1 | Input | Right |  | MRCC_N
U821 | A5 | 35 | U221 | D1 | 15 | ESP_VSPI_MOSI | Output | Left
U822 | A4 | 35 | U222 | E1 | 15 | ADV_R_0 | Input | Right
U823 | B4 | 35 | U223 | E2 | 15 | ESP_VSPI_CS | Output | Left
U824 | A3 | 35 | U224 | F2 | 15 | ADV_G_7 | NC | Right
U825 | D4 | 35 | U225 | F4 | 14 | ADV_INT | Output | Left |  | SRCC_N
U826 | C4 | 35 | U226 | G4 | 14 | ADV_G_6 | NC | Right |  | SRCC_P
U827 | C3 | 35 | U227 | G1 | 15 | NC | Output | Left
U828 | C2 | 35 | U228 | G2 | 15 | ADV_G_5 | NC | Right
U829 | B2 | 35 | U229 | H4 | 14 | NC | Output | Left
U830 | A2 | 35 | U230 | J4 | 14 | ADV_G_4 | Input | Right
U831 | C1 | 35 | U231 | H1 | 14 | NC | Output | Left
U832 | B1 | 35 | U232 | H2 | 14 | ADV_G_3 | Input | Right
U833 | E2 | 35 | U233 | G5_VREF | 14 | NC | Output | Left |  | MRCC_P
U834 | D1 | 35 | U234 | H9 | 14 | ADV_G_2 | Input | Right
U835 | E3 | 35 | U235 | L2 | 14 | NC | Output | Left |  | SRCC_N
U836 | D3 | 35 | U236 | M2 | 14 | ADV_SCL | Input | Right |  | SRCC_P
U837 | F5 | 35 | U237 | N3 | 14 | ESP_INT | Output | Left |  | MRCC_P
U838 | E5 | 35 | U238 | N2 | 14 | ADV_SDA | Input | Right |  | MRCC_N
U839 | F2 | 35 | U239 | K5 | 14 | NC | Output | Left
U840 | E1 | 35 | U240 | L5 | 14 | EXP_02 | Inout | Right
U841 | F4 | 35 | U241 | L4 | 14 | NC | Output | Left
U842 | F3 | 35 | U242 | M4 | 14 | EXP_04 | Inout | Right
U843 | G2 | 35 | U243 | P3 | 14 | EXP_08 | Inout | Left |  | MRCC_P
U844 | G1 | 35 | U244 | R3 | 14 | EXP_10 | Inout | Right |  | MRCC_N
U845 | H2 | 35 | U245 | J1 | 13 | EXP_12 | Inout | Left
U846 | H1 | 35 | U246 | K1 | 13 | EXP_16 | Inout | Right
U847 | K1 | 35 | U247 | M5_VREF | 13 | EXP_18 | Inout | Left
U848 | J1 | 35 | U248 | M6 | 13 | EXP_20 | Inout | Right
U849 | L3 | 35 | U249 | T3 | 13 | EXP_22 | Inout | Left
U850 | L2 | 35 | U250 | T4 | 13 | EXP_24 | Inout | Right
U851 | H5 | 35 | U251 | P5_VREF | 13 | EXP_26 | Inout | Left
U852 | H4 | 35 | U252 | P6 | 13 | EXP_28 | Inout | Right
U853 | J3 | 35 | U253 | M1 | 13 | EXP_30 | Inout | Left
U854 | H3 | 35 | U254 | N1 | 13 | EXP_32 | Inout | Right
U855 | K3 | 35 | U255 | P1 | 13 | EXP_34 | Inout | Left
U856 | K2 | 35 | U256 | R1 | 13 | EXP_35 | Inout | Right
U857 | L4 | 34 | U257 | R2 | 13 | NC | Output | Left
U858 | M4 | 34 | U258 | T2 | 13 | NC | Input | Right
U859 | N3 | 34 | U259 | U1 | 13 | NC | Output | Left
U860 | N2 | 34 | U260 | U2 | 13 | NC | Input | Right
U861 |  |  | U261 |  |  | 3V3 | Power input | Left
U862 |  |  | U262 |  |  | 3V3 | Power input | Right
U863 |  |  | U263 |  |  | VIN5V | Power input | Left
U864 |  |  | U264 |  |  | VIN5V | Power input | Right

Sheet: AARS v3.0
a7t34 | Pin a7t | Bank | a7t100 | Func a7t100 | Bank | Function | Direction | Orientation | 35T caps | 100T caps | VREF pin
U701 |  |  | U401 |  |  | GND | Power input | Left
U702 |  |  | U402 |  |  | GND | Power input | Right
U703 |  |  | U403 |  |  | 3V3 | Power output | Left
U704 |  |  | U404 |  |  | 3V3 | Power output | Right
U705 |  |  | U405 |  |  | GND | Bidirectional | Left
U706 |  |  | U406 |  |  | GND | Unspecified | Right
U707 | M12 | 14 | U407 | D26 | 15 | ADV_VSYNC | Output | Left
U708 | N13 | 14 | U408 | E26 | 15 | ADV_HSYNC | Output | Right
U709 | N14 | 14 | U409 | D25 | 15 | ADV_DE | Output | Left
U710 | N16 | 14 | U410 | E25 | 15 | ADV_B_0 | Output | Right
U711 | P15 | 14 | U411 | G26 | 15 | ADV_B_1 | Output | Left
U712 | P16 | 14 | U412 | H26 | 15 | ADV_B_2 | Output | Right
U713 | R15 | 14 | U413 | E23 | 15 | ADV_B_3 | Output | Left
U714 | R16 | 14 | U414 | F23 | 15 | ADV_B_4 | Output | Right
U715 | T14 | 14 | U415 | F22 | 15 | ADV_B_5 | Output | Left
U716 | T15 | 14 | U416 | G22 | 15 | ADV_B_6 | Output | Right
U717 | P13 | 14 | U417 | J26 | 15 | ADV_B_7 | Output | Left
U718 | P14 | 14 | U418 | J25 | 15 | ADV_G_0 | Output | Right
U719 | T13 | 14 | U419 | G21 | 15 | ADV_CLK | Output | Left |  | SRCC_N
U720 | R13 | 14 | U420 | G20 | 15 | ADV_G_1 | Output | Right |  | SRCC_P
U721 | T12 | 14 | U421 | H22 | 15 | ADV_I2S0 | Output | Left
U722 | R12 | 14 | U422 | H21 | 15 | ADV_I2S1 | Output | Right |  | MRCC_P
U723 | L13 | 14 | U423 | J21 | 15 | ADV_SCLK | Output | Left |  | MRCC_N
U724 | N12 | 14 | U424 | K21 | 15 | ADV_LRCLK | Output | Right |  | MRCC_P
U725 | K12 | 14 | U425 | K26 | 14 | SDRAM_D15 | Inout | Left |  | MRCC_N
U726 | K13 | 14 | U426 | K25 | 14 | SDRAM_D14 | Inout | Right
U727 | P10 | 14 | U427 | K23 | 15 | SDRAM_D13 | Inout | Left
U728 | P11 | 14 | U428 | K22 | 15 | SDRAM_D12 | Inout | Right |  | SRCC_P
U729 | N9 | 14 | U429 | M26 | 14 | SDRAM_D11 | Inout | Left
U730 | P9 | 14 | U430 | N26 | 14 | SDRAM_D10 | Inout | Right
U731 | T10 | 14 | U431 | L23 | 14 | SDRAM_D9 | Inout | Left |  | SRCC_N
U732 | R11 | 14 | U432 | L22 | 14 | SDRAM_D8 | Inout | Right
U733 | T9 | 14 | U433 | P26 | 14 | SDRAM_DQMH | Output | Left
U734 | R10 | 14 | U434 | R26 | 14 | SDRAM_CLK | Output | Right
U735 | T8 | 14 | U435 | M25 | 14 | SDRAM_CKE | Power input | Left
U736 | R8 | 14 | U436 | M24 | 14 | SDRAM_A11 | Output | Right
U737 | T7 | 14 | U437 | N22 | 14 | SDRAM_A9 | Power input | Left
U738 | R7 | 14 | U438 | N21 | 14 | SDRAM_A8 | Bidirectional | Right
U739 | T5 | 14 | U439 | P24 | 14 | SDRAM_A7 | Power input | Left
U740 | R6 | 14 | U440 | P23 | 14 | SDRAM_A6 | Output | Right
U741 | P6 | 14 | U441 | P25 | 14 | SDRAM_A5 | Power input | Left
U742 | R5 | 14 | U442 | R25 | 14 | EXP_MTRON | Output | Right
U743 | N6 | 14 | U443 | T25 | 14 | SDRAM_A4 | Output | Left
U744 | M6 | 14 | U444 | T24 | 14 | LED0 | Output | Right
U745 | L5 | 34 | U445 | V21 | 13 | JS_MOSI | Output | Left |  | MRCC_N | *Needs to be patched, because of an error in V3.0
U746 | P5 | 34 | U446 | U21 | 13 | JS_MISO | Output | Right |  | MRCC_P
U747 | T4 | 34 | U447 | W23 | 13 | JS_CS | Output | Left
U748 | T3 | 34 | U448 | V23 | 13 | JS_INTA | Output | Right
U749 | R3 | 34 | U449 | Y23 | 13 | SDRAM_A12 | Output | Left |  | SRCC_N
U750 | T2 | 34 | U450 | Y22 | 13 | JS_SCK | Output | Right |  | SRCC_P
U751 | R2 | 34 | U451 | AA25 | 13 | MAX_I2S0 | Output | Left
U752 | R1 | 34 | U452 | Y25 | 13 | LED1 | Output | Right
U753 | M5 | 34 | U453 | Y21 | 13 | PS2_CLK2 | Output | Left |  | SRCC_N
U754 | N4 | 34 | U454 | W21 | 13 | LED2 | Output | Right |  | SRCC_P
U755 | P4 | 34 | U455 | AC24 | 13 | PS2_DAT2 | Output | Left
U756 | P3 | 34 | U456 | AB24 | 13 | LED3 | Output | Right
U757 | N1 | 34 | U457 | Y26 | 13 | MAX_SCLK | Power input | Left
U758 | P1 | 34 | U458 | W25 | 13 | PS2_CLK1 | Power input | Right
U759 | M2 | 34 | U459 | AC26 | 13 | MAX_LRCLK | Power input | Left
U760 | M1 | 34 | U460 | AB26 | 13 | PS2_DAT1 | Power input | Right
U761 |  |  | U461 |  |  | GND | Power input | Left
U762 |  |  | U462 |  |  | GND | Power input | Right
U763 |  |  | U463 |  |  | VIN5V | Power input | Left
U764 |  |  | U464 |  |  | VIN5V | Power input | Right
U801 |  |  | U201 |  |  | GND | GND | Left
U802 |  |  | U202 |  |  | GND | GND | Right
U803 |  |  | U203 |  |  | 3V3 | Power input | Left
U804 |  |  | U204 |  |  | 3V3 | Power input | Right
U805 |  |  | U205 |  |  | GND | GND | Left
U806 |  |  | U206 |  |  | GND | GND | Right
U807 | B7 | 35 | U207 | A5 | 35 | ADV_R_6 | Output | Left
U808 | A7 | 35 | U208 | B5 | 35 | ADV_R_7 | Output | Right
U809 | B6 | 35 | U209 | A4 | 35 | ADV_R_4 | Output | Left
U810 | B5 | 35 | U210 | B4 | 35 | ADV_R_5 | Output | Right
U811 | E6 | 35 | U211 | A2 | 35 | ADV_R_2 | Output | Left
U812 | K5 | 35 | U212 | A3 | 35 | ADV_R_3 | Output | Right
U813 | J5 | 35 | U213 | C2 | 35 | ADV_R_0 | Output | Left
U814 | J4 | 35 | U214 | B2 | 35 | ADV_R_1 | Output | Right
U815 | G5 | 35 | U215 | D4 | 35 | ESP_VSPI_CLK | Output | Left |  | SRCC_P
U816 | G4 | 35 | U216 | C4 | 35 | ADV_G_7 | Output | Right |  | SRCC_N
U817 | C7 | 35 | U217 | D5 | 35 | ADV_G_6 | Output | Left |  | MRCC_N
U818 | C6 | 35 | U218 | E5 | 35 | ADV_G_5 | Output | Right
U819 | D6 | 35 | U219 | B1 | 35 | ESP_VSPI_MISO | Output | Left
U820 | D5 | 35 | U220 | C1 | 35 | ADV_G_4 | Output | Right |  | MRCC_N
U821 | A5 | 35 | U221 | D1 | 35 | ESP_VSPI_MOSI | Output | Left
U822 | A4 | 35 | U222 | E1 | 35 | ADV_G_3 | Output | Right
U823 | B4 | 35 | U223 | E2 | 35 | ESP_VSPI_CS | Output | Left
U824 | A3 | 35 | U224 | F2 | 35 | ADV_G_2 | Output | Right
U825 | D4 | 35 | U225 | F4 | 35 | ADV_INT | Output | Left |  | SRCC_N
U826 | C4 | 35 | U226 | G4 | 35 | ADV_SCL | NC | Right |  | SRCC_P
U827 | C3 | 35 | U227 | G1 | 35 | ESP_INT | Output | Left
U828 | C2 | 35 | U228 | G2 | 35 | ADV_SDA | NC | Right
U829 | B2 | 35 | U229 | H4 | 35 | SDRAM_D1 | Output | Left
U830 | A2 | 35 | U230 | J4 | 35 | SDRAM_D0 | Input | Right
U831 | C1 | 35 | U231 | H1 | 34 | SDRAM_D3 | Output | Left
U832 | B1 | 35 | U232 | H2 | 34 | SDRAM_D2 | Input | Right
U833 | E2 | 35 | U233 | G9 | 35 | SDRAM_D5 | Output | Left |  | MRCC_P | VREF
U834 | D1 | 35 | U234 | H9 | 35 | SDRAM_D4 | Input | Right
U835 | E3 | 35 | U235 | L2 | 34 | SDRAM_D7 | Output | Left |  | SRCC_N
U836 | D3 | 35 | U236 | M2 | 34 | SDRAM_D6 | Input | Right |  | SRCC_P
U837 | F5 | 35 | U237 | N3 | 34 | SDRAM_WE | Output | Left |  | MRCC_P
U838 | E5 | 35 | U238 | N2 | 34 | SDRAM_DQML | Input | Right |  | MRCC_N
U839 | F2 | 35 | U239 | K5 | 34 | SDRAM_RAS | Output | Left
U840 | E1 | 35 | U240 | L5 | 34 | SDRAM_CAS | Inout | Right
U841 | F4 | 35 | U241 | L4 | 34 | SDRAM_BA0 | Output | Left
U842 | F3 | 35 | U242 | M4 | 34 | SDRAM_CS | Inout | Right
U843 | G2 | 35 | U243 | P3 | 34 | SDRAM_A10 | Inout | Left |  | MRCC_P
U844 | G1 | 35 | U244 | R3 | 34 | SDRAM_BA1 | Inout | Right |  | MRCC_N
U845 | H2 | 35 | U245 | J1 | 34 | SDRAM_A1 | Inout | Left
U846 | H1 | 35 | U246 | K1 | 34 | SDRAM_A0 | Inout | Right
U847 | K1 | 35 | U247 | M5 | 34 | SDRAM_A3 | Inout | Left |  |  | VREF
U848 | J1 | 35 | U248 | M6 | 34 | SDRAM_A2 | Inout | Right
U849 | L3 | 35 | U249 | T3 | 34 | EXP_SEL0 | Inout | Left
U850 | L2 | 35 | U250 | T4 | 34 | EXP_SEL1 | Inout | Right
U851 | H5 | 35 | U251 | P5 | 34 | EXP_DIR | Inout | Left |  |  | VREF
U852 | H4 | 35 | U252 | P6 | 34 | EXP_STEP | Inout | Right
U853 | J3 | 35 | U253 | M1 | 34 | EXP_CHNG | Inout | Left
U854 | H3 | 35 | U254 | N1 | 34 | EXP_INDEX | Inout | Right
U855 | K3 | 35 | U255 | P1 | 34 | EXP_RDY | Inout | Left
U856 | K2 | 35 | U256 | R1 | 34 | EXP_DKRD | Inout | Right
U857 | L4 | 34 | U257 | R2 | 34 | EXP_TRK0 | Output | Left
U858 | M4 | 34 | U258 | T2 | 34 | EXP_DKWDB | Input | Right
U859 | N3 | 34 | U259 | U1 | 34 | EXP_DKWEB | Output | Left
U860 | N2 | 34 | U260 | U2 | 34 | EXP_SIDE | Input | Right
U861 |  |  | U261 |  |  | GND | Power input | Left
U862 |  |  | U262 |  |  | GND | Power input | Right
U863 |  |  | U263 |  |  | VIN5V | Power input | Left
U864 |  |  | U264 |  |  | VIN5V | Power input | Right
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

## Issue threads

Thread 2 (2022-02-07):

Migration to current QMTech Boards

mrgo0se, 2022-02-07:
Hi,

Great project, thank you for your efforts.

Are you planning any hardware updates in the future to support current QMTech Xilinx boards and/or refresh the components on the board that are becoming difficult to find?

It appears that the supported FPGA modules are no longer available direct from QMTech and that the linked eBay seller that is still active has a fairly poor rating.

If you're not planning a future hardware revision would it be possible to add some documentation on migrating the project to other QMTech boards? I understand that most QMTech Xilinx modules break out a similar subset of the available pins from their FPGAs to a standard header. Some discussion of what would be required and the best candidate QM modules would be great.

Cheers.

ranzbak, 2022-02-15:
I'll have a look at Ali express, and see what boards are available, and which ones I can design a PCB for.
Thanks for the feedback!

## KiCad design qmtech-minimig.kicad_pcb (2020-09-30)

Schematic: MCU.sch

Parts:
C2, C3, C7, C8, C10: 100nF; C_0603_1608Metric
C4: 1uF; C_0603_1608Metric
C9, C42: 4.7uF; C_0805_2012Metric
C44, C47: 10nF; C_0603_1608Metric
D1, D2: GREEN; LED_0603_1608Metric
D4: LED5; LED_0603_1608Metric
D11: LED4; LED_0603_1608Metric
IC1: ESP32-WROVER-B_(16MB); ESP32WROVERIB16MB; Manufacturer_Part_Number ESP32-WROVER-B (16MB); Mouser Part Number 356-ESP32-WROB(16MB)
J4: 10118193-0001LF; FCI_10118193-0001LF
Q1, Q2: MMBT2222A; SOT-23
R3: 47K; R_0603_1608Metric
R17: 10K; R_0603_1608Metric
R24, R27, R30, R31: 10k; R_0603_1608Metric
R25, R26, R38, R39: 1k; R_0603_1608Metric
SW1: SW_Push; SW_SPST_EVQQ2
U4: INTERFACE-CP2102-GMR(QFN28); QFN-28-1EP_5x5mm_P0.5mm_EP3.35x3.35mm
U5V1: USB5V; TestPoint_THTPad_1.0x1.0mm_Drill0.5mm
UG1: GND; TestPoint_THTPad_1.0x1.0mm_Drill0.5mm

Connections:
3V3: C3.2, C4.2, C44.2, C47.1, D1.2, D2.2, D4.2, D11.2, IC1.2, R3.1, R17.1, R24.2, R31.2; also elsewhere on the board
/MCU/D+: J4.3 (D+), U4.4
/MCU/D-: J4.2 (D-), U4.5
/MCU/LED0: IC1.33, R39.1
/MCU/LED1: IC1.36, R38.1
/MCU/RST_n: R24.1, U4.9
ADV_INT: IC1.7; also elsewhere on the board
ADV_SCL: IC1.12; also elsewhere on the board
ADV_SDA: IC1.11; also elsewhere on the board
ESP_FLASH: IC1.25, Q2.3, R31.1
ESP_INT: IC1.10, R3.2; also elsewhere on the board
ESP_RST: IC1.3, Q1.3, R17.2, SW1.2
ESP_SD_CLK: IC1.13; also elsewhere on the board
ESP_SD_CMD: IC1.23; also elsewhere on the board
ESP_SD_DATA0: IC1.24; also elsewhere on the board
ESP_SD_DATA1: IC1.26; also elsewhere on the board
ESP_SD_DATA2: IC1.14; also elsewhere on the board
ESP_SD_DATA3: IC1.16; also elsewhere on the board
ESP_SD_SW: IC1.6; also elsewhere on the board
ESP_SD_VCC_EN: IC1.8; also elsewhere on the board
ESP_UART0_RX: IC1.34, R25.2, U4.26
ESP_UART0_TX: IC1.35, R26.2, U4.25
ESP_VSPI_CLK: IC1.30; also elsewhere on the board
ESP_VSPI_CS: IC1.9; also elsewhere on the board
ESP_VSPI_MISO: IC1.31; also elsewhere on the board
ESP_VSPI_MOSI: IC1.37; also elsewhere on the board
GND: C2.2, C3.1, C4.1, C7.2, C8.2, C9.2, C10.1, C42.2, C44.1, C47.2, IC1.1, IC1.15, IC1.38, IC1.39, J4.5 (GND), J4.S1 (SHIELD), J4.S2 (SHIELD), J4.S3 (SHIELD), J4.S4 (SHIELD), J4.S5 (SHIELD), J4.S6 (SHIELD), SW1.1, U4.3, U4.29, UG1.1; also elsewhere on the board
unnamed: C2.1, IC1.4
unnamed: C7.1, IC1.5
unnamed: C10.2, C42.1, U4.6
unnamed: D1.1, R25.1
unnamed: D2.1, R26.1
unnamed: D4.1, R38.2
unnamed: D11.1, R39.2
unnamed: Q1.1, R27.1
unnamed: Q2.1, R30.1
USB_DTR: Q2.2, R27.2, U4.28
USB_RTS: Q1.2, R30.2, U4.24
VUSB5V: C8.1, C9.1, J4.1 (VUSB), U4.7, U4.8, U5V1.1

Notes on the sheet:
Reset button
RF decoupling SPI
Decouple the USB signal

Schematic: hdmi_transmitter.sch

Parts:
1V8, 3V3: TestPoint; TestPoint_THTPad_1.0x1.0mm_Drill0.5mm
ADV7511KSTZ1: adv7511kstz; LQFP-100_14x14mm_P0.5mm
C1, C32, C33, C34, C35, C36, C37, C38, C39, C40, C41, C48, C49: 100nF; C_0603_1608Metric
C21, C22, C23, C29, C30, C31: 10uF; C_0805_2012Metric
D30: 1N4148; D_SOD-323
GND2: GND; TestPoint_THTPad_1.0x1.0mm_Drill0.5mm
J9: 47151-0001
L1, L2, L3, L4: 10uH; L_0805_2012Metric
R18, R19, R42, R43: 2k; R_0603_1608Metric
R34, R56, R60, R62: 10k; R_0603_1608Metric
R41, R54, R55, R58: 2K; R_0603_1608Metric
R57: 887; R_0603_1608Metric
R59: 27k; R_0603_1608Metric
R61: 27; R_0603_1608Metric
TP1: TP_SCL; TestPoint_Pad_D1.0mm
TP2: TP_SDA; TestPoint_Pad_D1.0mm
TP3: TP_GND; TestPoint_Pad_D1.0mm
U1: TPD12S520DBT; TSSOP-38_4.4x9.7mm_P0.5mm
U3: LT1963AxST-1.8; SOT-223-3_TabPin2
X1: MCSJK-3N-16.00-3.3-50-B; Oscillator_SMD_Abracon_ASE-4Pin_3.2x2.5mm

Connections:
3V3: 3V3.1, ADV7511KSTZ1.47, C1.2, C29.1, C49.1, R18.1, R19.1, R41.2, R59.1, R60.1, U1.2, U3.1, X1.4; also elsewhere on the board
/HDMI transmitter/1V8: 1V8.1, C30.1, L1.2, L2.2, L3.2, L4.2, U3.3
/HDMI transmitter/HDMI5V: J9.18, R34.2, R42.1, R43.1, R54.1, R58.2, U1.1
ADV_AVDD: ADV7511KSTZ1.29, ADV7511KSTZ1.34, ADV7511KSTZ1.41, C22.1, C37.1, C40.2, C41.2, L2.1
ADV_BGVDD: ADV7511KSTZ1.26, C31.1, C36.1, L4.1
ADV_B_0: ADV7511KSTZ1.92; also elsewhere on the board
ADV_B_1: ADV7511KSTZ1.91; also elsewhere on the board
ADV_B_2: ADV7511KSTZ1.90; also elsewhere on the board
ADV_B_3: ADV7511KSTZ1.89; also elsewhere on the board
ADV_B_4: ADV7511KSTZ1.88; also elsewhere on the board
ADV_B_5: ADV7511KSTZ1.87; also elsewhere on the board
ADV_B_6: ADV7511KSTZ1.86; also elsewhere on the board
ADV_B_7: ADV7511KSTZ1.85; also elsewhere on the board
ADV_CEC: ADV7511KSTZ1.48, D30.1, U1.16
ADV_CECCLK: ADV7511KSTZ1.50, R61.1
ADV_CEC_C: J9.13, U1.23
ADV_CLK: ADV7511KSTZ1.79; also elsewhere on the board
ADV_DDCSCL: ADV7511KSTZ1.53, R58.1, U1.17
ADV_DDCSCL_C: J9.15, R42.2, U1.22
ADV_DDCSDA: ADV7511KSTZ1.54, R54.2, U1.18
ADV_DDCSDA_C: J9.16, R43.2, U1.21
ADV_DE: ADV7511KSTZ1.97; also elsewhere on the board
ADV_DVDD: ADV7511KSTZ1.1, ADV7511KSTZ1.19, ADV7511KSTZ1.49, ADV7511KSTZ1.76, ADV7511KSTZ1.77, C21.1, C33.1, C35.1, C38.2, C39.2, L1.1
ADV_G_0: ADV7511KSTZ1.80; also elsewhere on the board
ADV_G_1: ADV7511KSTZ1.78; also elsewhere on the board
ADV_G_2: ADV7511KSTZ1.74; also elsewhere on the board
ADV_G_3: ADV7511KSTZ1.73; also elsewhere on the board
ADV_G_4: ADV7511KSTZ1.72; also elsewhere on the board
ADV_G_5: ADV7511KSTZ1.71; also elsewhere on the board
ADV_G_6: ADV7511KSTZ1.70; also elsewhere on the board
ADV_G_7: ADV7511KSTZ1.69; also elsewhere on the board
ADV_HPD: ADV7511KSTZ1.30, R62.1, U1.19
ADV_HPD_C: J9.19, R56.2, U1.20
ADV_HSYNC: ADV7511KSTZ1.98; also elsewhere on the board
ADV_I2S0: ADV7511KSTZ1.12; also elsewhere on the board
ADV_I2S1: ADV7511KSTZ1.13; also elsewhere on the board
ADV_INT: ADV7511KSTZ1.45, R41.1; also elsewhere on the board
ADV_LRCLK: ADV7511KSTZ1.17; also elsewhere on the board
ADV_PLVDD: ADV7511KSTZ1.21, ADV7511KSTZ1.24, ADV7511KSTZ1.25, C23.1, C32.2, C34.2, L3.1
ADV_R_0: ADV7511KSTZ1.64; also elsewhere on the board
ADV_R_1: ADV7511KSTZ1.63; also elsewhere on the board
ADV_R_2: ADV7511KSTZ1.62; also elsewhere on the board
ADV_R_3: ADV7511KSTZ1.61; also elsewhere on the board
ADV_R_4: ADV7511KSTZ1.60; also elsewhere on the board
ADV_R_5: ADV7511KSTZ1.59; also elsewhere on the board
ADV_R_6: ADV7511KSTZ1.58; also elsewhere on the board
ADV_R_7: ADV7511KSTZ1.57; also elsewhere on the board
ADV_SCL: ADV7511KSTZ1.55, R18.2, TP1.1; also elsewhere on the board
ADV_SCLK: ADV7511KSTZ1.16; also elsewhere on the board
ADV_SDA: ADV7511KSTZ1.56, R19.2, TP2.1; also elsewhere on the board
ADV_TX0+: ADV7511KSTZ1.36, J9.7, U1.10, U1.29
ADV_TX0-: ADV7511KSTZ1.35, J9.9, U1.12, U1.27
ADV_TX1+: ADV7511KSTZ1.40, J9.4, U1.7, U1.32
ADV_TX1-: ADV7511KSTZ1.39, J9.6, U1.9, U1.30
ADV_TX2+: ADV7511KSTZ1.43, J9.1, U1.4, U1.35
ADV_TX2-: ADV7511KSTZ1.42, J9.3, U1.6, U1.33
ADV_TXC+: ADV7511KSTZ1.33, J9.10, U1.13, U1.26
ADV_TXC-: ADV7511KSTZ1.32, J9.12, U1.15, U1.24
ADV_VSYNC: ADV7511KSTZ1.2; also elsewhere on the board
GND: ADV7511KSTZ1.3, ADV7511KSTZ1.4, ADV7511KSTZ1.5, ADV7511KSTZ1.6, ADV7511KSTZ1.7, ADV7511KSTZ1.8, ADV7511KSTZ1.9, ADV7511KSTZ1.10, ADV7511KSTZ1.11, ADV7511KSTZ1.14, ADV7511KSTZ1.15, ADV7511KSTZ1.18, ADV7511KSTZ1.20, ADV7511KSTZ1.22, ADV7511KSTZ1.23, ADV7511KSTZ1.27, ADV7511KSTZ1.31, ADV7511KSTZ1.37, ADV7511KSTZ1.44, ADV7511KSTZ1.51, ADV7511KSTZ1.52, ADV7511KSTZ1.65, ADV7511KSTZ1.66, ADV7511KSTZ1.67, ADV7511KSTZ1.68, ADV7511KSTZ1.75, ADV7511KSTZ1.81, ADV7511KSTZ1.82, ADV7511KSTZ1.83, ADV7511KSTZ1.84, ADV7511KSTZ1.93, ADV7511KSTZ1.94, ADV7511KSTZ1.95, ADV7511KSTZ1.96, ADV7511KSTZ1.99, ADV7511KSTZ1.100, C1.1, C21.2, C22.2, C23.2, C29.2, C30.2, C31.2, C32.1, C33.2, C34.1, C35.2, C36.2, C37.2, C38.1, C39.1, C40.1, C41.1, C48.1, C49.2, GND2.1, J9.17, R55.2, R56.1, R57.2, R62.2, TP3.1, U1.3, U1.5, U1.8, U1.11, U1.14, U1.25, U1.28, U1.31, U1.34, U1.36, U3.2, X1.2; also elsewhere on the board
unnamed: ADV7511KSTZ1.28, R57.1
unnamed: ADV7511KSTZ1.38, R55.1
unnamed: C48.2, U1.37
unnamed: D30.2, R59.2
unnamed: R60.2, X1.1
unnamed: R61.2, X1.3
VIN5V: R34.1; also elsewhere on the board

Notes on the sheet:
I2C bus resistors
CEC Clock Generator
ESD protection IC
1V8 linear regulator
HDMI Plug
I2C Test points

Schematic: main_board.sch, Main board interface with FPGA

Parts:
C67: 22uF; CP_Elec_5x5.4
D7: 3; LED_0603_1608Metric
D8: 2; LED_0603_1608Metric
D9: 1; LED_0603_1608Metric
D10: 0; LED_0603_1608Metric
R50, R51, R52, R53: 1k; R_0603_1608Metric
U2: QM_XC7A35T_DDR3; QM_XC7A35T_DDR3_Daughterboard_rev2

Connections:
3V3: D7.2, D8.2, D9.2, D10.2, U2.U73, U2.U74, U2.U83, U2.U84; also elsewhere on the board
/Main Board/LED0: U2.U745; also elsewhere on the board
/Main Board/LED1: U2.U752; also elsewhere on the board
/Main Board/LED2: U2.U754; also elsewhere on the board
/Main Board/LED3: U2.U756; also elsewhere on the board
ADV_B_0: U2.U710; also elsewhere on the board
ADV_B_1: U2.U711; also elsewhere on the board
ADV_B_2: U2.U712; also elsewhere on the board
ADV_B_3: U2.U713; also elsewhere on the board
ADV_B_4: U2.U714; also elsewhere on the board
ADV_B_5: U2.U715; also elsewhere on the board
ADV_B_6: U2.U716; also elsewhere on the board
ADV_B_7: U2.U717; also elsewhere on the board
ADV_CLK: U2.U719; also elsewhere on the board
ADV_DE: U2.U79; also elsewhere on the board
ADV_G_0: U2.U718; also elsewhere on the board
ADV_G_1: U2.U720; also elsewhere on the board
ADV_G_2: U2.U824; also elsewhere on the board
ADV_G_3: U2.U822; also elsewhere on the board
ADV_G_4: U2.U820; also elsewhere on the board
ADV_G_5: U2.U818; also elsewhere on the board
ADV_G_6: U2.U817; also elsewhere on the board
ADV_G_7: U2.U816; also elsewhere on the board
ADV_HSYNC: U2.U78; also elsewhere on the board
ADV_I2S0: U2.U721; also elsewhere on the board
ADV_I2S1: U2.U722; also elsewhere on the board
ADV_INT: U2.U825; also elsewhere on the board
ADV_LRCLK: U2.U724; also elsewhere on the board
ADV_R_0: U2.U813; also elsewhere on the board
ADV_R_1: U2.U814; also elsewhere on the board
ADV_R_2: U2.U811; also elsewhere on the board
ADV_R_3: U2.U812; also elsewhere on the board
ADV_R_4: U2.U89; also elsewhere on the board
ADV_R_5: U2.U810; also elsewhere on the board
ADV_R_6: U2.U87; also elsewhere on the board
ADV_R_7: U2.U88; also elsewhere on the board
ADV_SCL: U2.U826; also elsewhere on the board
ADV_SCLK: U2.U723; also elsewhere on the board
ADV_SDA: U2.U828; also elsewhere on the board
ADV_VSYNC: U2.U77; also elsewhere on the board
ESP_INT: U2.U827; also elsewhere on the board
ESP_VSPI_CLK: U2.U815; also elsewhere on the board
ESP_VSPI_CS: U2.U823; also elsewhere on the board
ESP_VSPI_MISO: U2.U819; also elsewhere on the board
ESP_VSPI_MOSI: U2.U821; also elsewhere on the board
EXP_CHNG: U2.U853; also elsewhere on the board
EXP_DIR: U2.U851; also elsewhere on the board
EXP_DKRD: U2.U856; also elsewhere on the board
EXP_DKWDB: U2.U858; also elsewhere on the board
EXP_DKWEB: U2.U859; also elsewhere on the board
EXP_INDEX: U2.U854; also elsewhere on the board
EXP_MTRON: U2.U743; also elsewhere on the board
EXP_RDY: U2.U855; also elsewhere on the board
EXP_SEL0: U2.U849; also elsewhere on the board
EXP_SEL1: U2.U850; also elsewhere on the board
EXP_SIDE: U2.U860; also elsewhere on the board
EXP_STEP: U2.U852; also elsewhere on the board
EXP_TRK0: U2.U857; also elsewhere on the board
GND: C67.2, U2.U71, U2.U72, U2.U75, U2.U76, U2.U81, U2.U82, U2.U85, U2.U86, U2.U761, U2.U762, U2.U861, U2.U862; also elsewhere on the board
JS_CS: U2.U748; also elsewhere on the board
JS_INTA: U2.U749; also elsewhere on the board
JS_MISO: U2.U747; also elsewhere on the board
JS_MOSI: U2.U746; also elsewhere on the board
JS_SCK: U2.U750; also elsewhere on the board
MAX_I2S0: U2.U751; also elsewhere on the board
MAX_LRCLK: U2.U759; also elsewhere on the board
MAX_SCLK: U2.U757; also elsewhere on the board
unnamed 169: D7.1; also elsewhere on the board
unnamed 170: D8.1; also elsewhere on the board
unnamed 171: D9.1; also elsewhere on the board
unnamed 172: D10.1; also elsewhere on the board
PS2_CLK1: U2.U758; also elsewhere on the board
PS2_CLK2: U2.U753; also elsewhere on the board
PS2_DAT1: U2.U760; also elsewhere on the board
PS2_DAT2: U2.U755; also elsewhere on the board
SDRAM_A0: U2.U846; also elsewhere on the board
SDRAM_A1: U2.U845; also elsewhere on the board
SDRAM_A2: U2.U848; also elsewhere on the board
SDRAM_A3: U2.U847; also elsewhere on the board
SDRAM_A4: U2.U744; also elsewhere on the board
SDRAM_A5: U2.U742; also elsewhere on the board
SDRAM_A6: U2.U741; also elsewhere on the board
SDRAM_A7: U2.U740; also elsewhere on the board
SDRAM_A8: U2.U739; also elsewhere on the board
SDRAM_A9: U2.U738; also elsewhere on the board
SDRAM_A10: U2.U843; also elsewhere on the board
SDRAM_A11: U2.U737; also elsewhere on the board
SDRAM_A12: U2.U736; also elsewhere on the board
SDRAM_BA0: U2.U841; also elsewhere on the board
SDRAM_BA1: U2.U844; also elsewhere on the board
SDRAM_CAS: U2.U840; also elsewhere on the board
SDRAM_CKE: U2.U735; also elsewhere on the board
SDRAM_CLK: U2.U734; also elsewhere on the board
SDRAM_CS: U2.U842; also elsewhere on the board
SDRAM_D0: U2.U830; also elsewhere on the board
SDRAM_D1: U2.U829; also elsewhere on the board
SDRAM_D2: U2.U832; also elsewhere on the board
SDRAM_D3: U2.U831; also elsewhere on the board
SDRAM_D4: U2.U834; also elsewhere on the board
SDRAM_D5: U2.U833; also elsewhere on the board
SDRAM_D6: U2.U836; also elsewhere on the board
SDRAM_D7: U2.U835; also elsewhere on the board
SDRAM_D8: U2.U732; also elsewhere on the board
SDRAM_D9: U2.U731; also elsewhere on the board
SDRAM_D10: U2.U730; also elsewhere on the board
SDRAM_D11: U2.U729; also elsewhere on the board
SDRAM_D12: U2.U728; also elsewhere on the board
SDRAM_D13: U2.U727; also elsewhere on the board
SDRAM_D14: U2.U726; also elsewhere on the board
SDRAM_D15: U2.U725; also elsewhere on the board
SDRAM_DQMH: U2.U733; also elsewhere on the board
SDRAM_DQML: U2.U838; also elsewhere on the board
SDRAM_RAS: U2.U839; also elsewhere on the board
SDRAM_WE: U2.U837; also elsewhere on the board
VIN5V: C67.1, U2.U763, U2.U764, U2.U863, U2.U864; also elsewhere on the board

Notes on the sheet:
LED indicators
Decoupling Cap

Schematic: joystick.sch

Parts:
C20, C24, C57: 100nF; C_0603_1608Metric
F2, F3: 100mA; Fuse_0805_2012Metric
J1, J2: DB9_Male; DSUB-9_Male_Horizontal_P2.77x2.84mm_EdgePinOffset7.70mm_Hou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
R2, R7, R12, R87: 10k; R_0603_1608Metric
RN1, RN2, RN3, RN4: 10K; R_Array_Convex_4x0603
U6: TXB0106PWR; SOP65P640X120-16N
U9: MCP23S17; SSOP-28_5.3x10.2mm_P0.65mm

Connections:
3V3: C20.2, R2.2, U6.2; also elsewhere on the board
/Joystick/JS_MISO_5V: U6.12, U9.14
/Joystick/JS_MOSI_5V: U6.11, U9.13
/Joystick/JS_SCK_5V: U6.10, U9.12
GND: C20.1, C24.1, C57.1, J1.0, J1.8, J2.0, J2.8, R7.2, R12.2, R87.2, U6.9, U9.10; also elsewhere on the board
J1IN5V: F3.1, J1.7, RN1.5, RN1.6, RN1.7, RN1.8, RN2.5, RN2.6, RN2.7, RN2.8
J2IN5V: F2.1, J2.7, RN3.5, RN3.6, RN3.7, RN3.8, RN4.5, RN4.6, RN4.7, RN4.8
JS1_1: J1.1, RN2.1, U9.21
JS1_2: J1.2, RN2.3, U9.23
JS1_3: J1.3, RN1.1, U9.24
JS1_4: J1.4, RN1.2, U9.25
JS1_5: J1.5, RN1.4, U9.27
JS1_6: J1.6, RN2.2, U9.22
JS1_9: J1.9, RN1.3, U9.26
JS2_1: J2.1, RN4.3, U9.7
JS2_2: J2.2, RN4.1, U9.5
JS2_3: J2.3, RN3.4, U9.4
JS2_4: J2.4, RN3.3, U9.3
JS2_5: J2.5, RN3.1, U9.1
JS2_6: J2.6, RN4.2, U9.6
JS2_9: J2.9, RN3.2, U9.2
JS_CS: U6.4; also elsewhere on the board
JS_CS_5V: U6.13, U9.11
JS_INTA: U6.3; also elsewhere on the board
JS_INTA_5V: U6.14, U9.20
JS_INTB: U6.1
JS_INTB_5V: U6.16, U9.19
JS_MISO: U6.5; also elsewhere on the board
JS_MOSI: U6.6; also elsewhere on the board
JS_SCK: U6.7; also elsewhere on the board
unnamed: R2.1, U6.8
unnamed: R7.1, U9.15, U9.16, U9.17
unnamed: R12.1, U9.28
unnamed: R87.1, U9.8
VIN5V: C24.2, C57.2, F2.2, F3.2, U6.15, U9.9, U9.18; also elsewhere on the board

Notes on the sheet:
5V SPI
I/O expander to SPI
Not strictly needed, can poll with the FPGA.

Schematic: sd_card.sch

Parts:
C6, C11, C12: 100nF; C_0603_1608Metric
J3: SCHA5B0200; ALPS_SCHA5B0200
Q3: BSS84; SOT-23
R20, R21, R22, R23: 10k; R_0603_1608Metric
R32: 100k; R_0603_1608Metric
R33: 10K; R_0603_1608Metric

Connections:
3V3: Q3.2, R32.1, R33.1; also elsewhere on the board
ESP_SD_CLK: J3.5, R20.2; also elsewhere on the board
ESP_SD_CMD: J3.3, R21.2; also elsewhere on the board
ESP_SD_DATA0: J3.7, R23.2; also elsewhere on the board
ESP_SD_DATA1: J3.8; also elsewhere on the board
ESP_SD_DATA2: J3.1; also elsewhere on the board
ESP_SD_DATA3: J3.2, R22.2; also elsewhere on the board
ESP_SD_SW: C12.1, J3.DT, R33.2; also elsewhere on the board
ESP_SD_VCC_EN: Q3.1, R32.2; also elsewhere on the board
GND: C6.2, C11.1, C12.2, J3.6, J3.CMN, J3.S1, J3.S2, J3.S3, J3.S4, J3.S5, J3.S6; also elsewhere on the board
unnamed: C6.1, C11.2, J3.4, Q3.3, R20.1, R21.1, R22.1, R23.1

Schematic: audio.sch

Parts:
C5: 10nF; C_0603_1608Metric
C27, C28, C51, C53, C54, C55: 1uF; C_0603_1608Metric
C45, C60: 100nF; C_0603_1608Metric
C50: 0.47uF; C_0603_1608Metric
C52: 2.2uF; C_0805_2012Metric
J5: AUDIO-CONNECTOR-6P-SMD-3440030P1; 6P-SMD-3.5
R9: 10k; R_0603_1608Metric
U8: INTERFACE-MAX9850ETI+-(QFN28); QFN-28-1EP_5x5mm_P0.5mm_EP3.35x3.35mm
X2: 11.2896MHz; Oscillator_SMD_SeikoEpson_SG210-4Pin_2.5x2.0mm

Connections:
3V3: C5.1, C27.2, C28.2, C54.2, C55.2, R9.2, U8.4, U8.16, U8.17, U8.26, X2.4; also elsewhere on the board
ADV_SCL: U8.27; also elsewhere on the board
ADV_SDA: U8.28; also elsewhere on the board
GND: C5.2, C27.1, C28.1, C45.1, C51.1, C52.1, C53.2, C54.1, C55.1, C60.1, J5.COM1, J5.COM2, U8.6, U8.7, U8.14, U8.24, U8.29, X2.2; also elsewhere on the board
HPL: J5.L, U8.19
HPR: J5.R, U8.18
HPS: J5.LS, U8.21
MAX_I2S0: U8.3; also elsewhere on the board
MAX_LRCLK: U8.1; also elsewhere on the board
MAX_SCLK: U8.2; also elsewhere on the board
unnamed: C45.2, U8.9
unnamed: C50.1, U8.23
unnamed: C50.2, U8.25
unnamed: C51.2, U8.13
unnamed: C52.2, U8.20, U8.22
unnamed: C53.1, U8.15
unnamed: C60.2, U8.10
unnamed: R9.1, X2.1
unnamed: U8.5, X2.3

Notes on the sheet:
Decouple Line ins
Negative voltage pump
I2S to FPGA

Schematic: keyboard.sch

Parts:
C43, C46: 10uF; C_0805_2012Metric
D12, D13, D28, D29: 3.6V; D_SOD-323_HandSoldering
F4, F5: 0.35A; Fuse_0805_2012Metric
P1, P2: Mini-DIN_6pins_ver3; Connector_Mini-DIN_Female_6Pin_2rows
R4, R5, R46, R47: 330; R_0603_1608Metric

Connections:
GND: C43.2, C46.2, D12.2, D13.2, D28.2, D29.2, P1.3, P1.7, P2.3, P2.7; also elsewhere on the board
unnamed: C43.1, F5.1, P2.4
unnamed: C46.1, F4.1, P1.4
unnamed: P1.1, R47.2
unnamed: P1.5, R46.2
unnamed: P2.1, R5.2
unnamed: P2.5, R4.2
PS2_CLK1: D28.1, R46.1; also elsewhere on the board
PS2_CLK2: D12.1, R4.1; also elsewhere on the board
PS2_DAT1: D29.1, R47.1; also elsewhere on the board
PS2_DAT2: D13.1, R5.1; also elsewhere on the board
VIN5V: F4.2, F5.2; also elsewhere on the board

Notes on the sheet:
Keyboard PS/2
Mouse PS/2

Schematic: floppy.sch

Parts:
+12V1: +12V; TestPoint_THTPad_1.0x1.0mm_Drill0.5mm
C13, C16, C18, C25: 100nF; C_0603_1608Metric
C14, C15, C17, C19: 22uF; C_0805_2012Metric
C26: 22uF; CP_Elec_5x5.4
D3: SS34_Zener; D_SMC
D5, D6: D_Schottky; D_0603_1608Metric
D33: LED; LED_0603_1608Metric
F1: 2A; Fuse_0805_2012Metric
GND1: GND; TestPoint_THTPad_1.0x1.0mm_Drill0.5mm
J7: Conn_02x13_Odd_Even; PinHeader_2x17_P2.54mm_Vertical
J8: Conn_01x04; JST-4-PTH-VERT
J10: DB23_Female_MountingHoles; DSUB-23_Female_Horizontal_P2.77x2.84mm_EdgePinOffset7.70mm_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
JP1: 12V Enable; PinHeader_1x02_P2.54mm_Vertical
L5: 22uH; L_10.4x10.4_H4.8
R6, R8, R10, R65, R68, R69, R70, R71, R72: 1k; R_0603_1608Metric
R35: 63k; R_0603_1608Metric
R36: 3.3k; R_0603_1608Metric
R37: 10k; R_0603_1608Metric
R40: 1M; R_0603_1608Metric
R73, R74, R75, R76, R77, R78, R79: 2.7k; R_0603_1608Metric
R80, R81, R82, R83, R84, R85, R86: 6k8; R_0603_1608Metric
U5: MT3608; SOT-23-6
U7: SN74LS06NSR; SO-14_5.3x10.2mm_P1.27mm

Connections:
EXP_CHNG: U7.2; also elsewhere on the board
EXP_DIR: R75.2, R82.2; also elsewhere on the board
EXP_DKRD: U7.8; also elsewhere on the board
EXP_DKWDB: R73.2, R80.2; also elsewhere on the board
EXP_DKWEB: R76.2, R84.2; also elsewhere on the board
EXP_INDEX: U7.4; also elsewhere on the board
EXP_MTRON: U7.12; also elsewhere on the board
EXP_RDY: U7.10; also elsewhere on the board
EXP_SEL0: R79.2, R85.2; also elsewhere on the board
EXP_SEL1: R74.2, R81.2; also elsewhere on the board
EXP_SIDE: R77.2, R86.2; also elsewhere on the board
EXP_STEP: R78.2, R83.2; also elsewhere on the board
EXP_TRK0: U7.6; also elsewhere on the board
GND: C13.2, C14.2, C15.2, C16.2, C17.1, C18.1, C19.2, C25.1, C26.2, D5.2, D6.2, D33.1, GND1.1, J7.1, J7.3, J7.5, J7.7, J7.9, J7.11, J7.13, J7.15, J7.17, J7.19, J7.21, J7.23, J7.25, J7.27, J7.29, J7.31, J7.33, J8.2, J8.3, J10.0 (PAD), J10.3, J10.4, J10.5, J10.6, J10.7, R36.2, R40.1, R80.1, R81.1, R82.1, R83.1, R84.1, R85.1, R86.1, U5.2, U7.7; also elsewhere on the board
H_EXP_02: J7.2, J10.11, U7.1
H_EXP_04: J7.4, J7.16, J10.8, U7.13
H_EXP_08: J7.8, J10.22, U7.3
H_EXP_10: D5.1, J7.10, R72.2, R79.1
H_EXP_12: D6.1, J7.12, J10.21, R8.2, R74.1
H_EXP_18: J7.18, J10.19, R68.2, R75.1
H_EXP_20: J7.20, J10.18, R69.2, R78.1
H_EXP_22: J7.22, J10.17, R6.2, R73.1
H_EXP_24: J7.24, J10.16, R70.2, R76.1
H_EXP_26: J7.26, J10.15, U7.5
H_EXP_28: J10.14
H_EXP_30: J7.30, J10.2, U7.9
H_EXP_32: J7.32, J10.13, R71.2, R77.1
H_EXP_34: J7.34, J10.1, U7.11
unnamed: C15.1, C16.1, JP1.1, L5.2, R37.1, R65.1, U5.5
unnamed: D3.2, L5.1, U5.1
unnamed: D33.2, R65.2
unnamed: J10.10, R10.2
unnamed: R35.2, R36.1, U5.3
unnamed: R37.2, U5.4
VFLP5V: C17.2, C18.2, C25.2, C26.1, F1.2, J8.1, J10.12, JP1.2, R6.1, R8.1, R10.1, R68.1, R69.1, R70.1, R71.1, R72.1, U7.14
VIN5V: F1.1; also elsewhere on the board
VIN12V: +12V1.1, C13.1, C14.1, C19.1, D3.1, J8.4, J10.23, R35.1, R40.2

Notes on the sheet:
12V power supply for the floppy drive
Floppy power connector
Alternative pereferal connector
Output lines, using invertor
Input lines with voltage devider
Schema based on http://amigadrive.blogspot.com/
Motor on, second pin

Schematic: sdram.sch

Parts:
C56, C58, C59, C61, C62, C63: 100nF; C_0603_1608Metric
C64, C65: 10uF; C_0805_2012Metric
IC2: AS4C16M16SA-6TCN; SOP80P1176X120-54N; Manufacturer_Part_Number AS4C16M16SA-6TCN; Mouser Part Number 913-4C16M16SA-6TCN

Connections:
3V3: C56.1, C58.1, C59.1, C61.1, C62.1, C63.1, C64.1, C65.1, IC2.1, IC2.3, IC2.9, IC2.14, IC2.27, IC2.43, IC2.49; also elsewhere on the board
GND: C56.2, C58.2, C59.2, C61.2, C62.2, C63.2, C64.2, C65.2, IC2.6, IC2.12, IC2.28, IC2.41, IC2.46, IC2.52, IC2.54; also elsewhere on the board
SDRAM_A0: IC2.23; also elsewhere on the board
SDRAM_A1: IC2.24; also elsewhere on the board
SDRAM_A2: IC2.25; also elsewhere on the board
SDRAM_A3: IC2.26; also elsewhere on the board
SDRAM_A4: IC2.29; also elsewhere on the board
SDRAM_A5: IC2.30; also elsewhere on the board
SDRAM_A6: IC2.31; also elsewhere on the board
SDRAM_A7: IC2.32; also elsewhere on the board
SDRAM_A8: IC2.33; also elsewhere on the board
SDRAM_A9: IC2.34; also elsewhere on the board
SDRAM_A10: IC2.22; also elsewhere on the board
SDRAM_A11: IC2.35; also elsewhere on the board
SDRAM_A12: IC2.36; also elsewhere on the board
SDRAM_BA0: IC2.20; also elsewhere on the board
SDRAM_BA1: IC2.21; also elsewhere on the board
SDRAM_CAS: IC2.17; also elsewhere on the board
SDRAM_CKE: IC2.37; also elsewhere on the board
SDRAM_CLK: IC2.38; also elsewhere on the board
SDRAM_CS: IC2.19; also elsewhere on the board
SDRAM_D0: IC2.2; also elsewhere on the board
SDRAM_D1: IC2.4; also elsewhere on the board
SDRAM_D2: IC2.5; also elsewhere on the board
SDRAM_D3: IC2.7; also elsewhere on the board
SDRAM_D4: IC2.8; also elsewhere on the board
SDRAM_D5: IC2.10; also elsewhere on the board
SDRAM_D6: IC2.11; also elsewhere on the board
SDRAM_D7: IC2.13; also elsewhere on the board
SDRAM_D8: IC2.42; also elsewhere on the board
SDRAM_D9: IC2.44; also elsewhere on the board
SDRAM_D10: IC2.45; also elsewhere on the board
SDRAM_D11: IC2.47; also elsewhere on the board
SDRAM_D12: IC2.48; also elsewhere on the board
SDRAM_D13: IC2.50; also elsewhere on the board
SDRAM_D14: IC2.51; also elsewhere on the board
SDRAM_D15: IC2.53; also elsewhere on the board
SDRAM_DQMH: IC2.39; also elsewhere on the board
SDRAM_DQML: IC2.15; also elsewhere on the board
SDRAM_RAS: IC2.18; also elsewhere on the board
SDRAM_WE: IC2.16; also elsewhere on the board

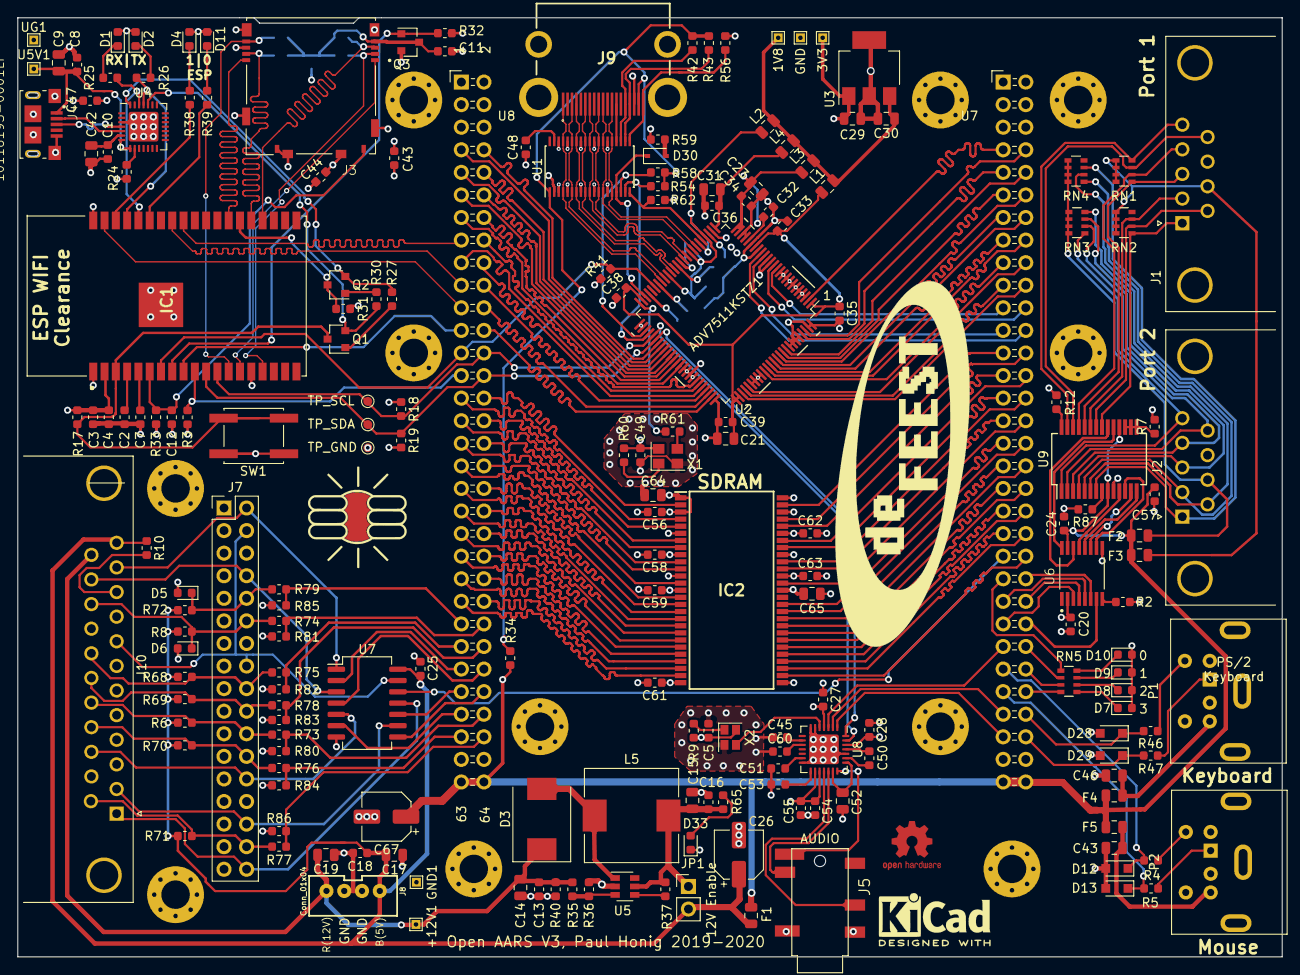
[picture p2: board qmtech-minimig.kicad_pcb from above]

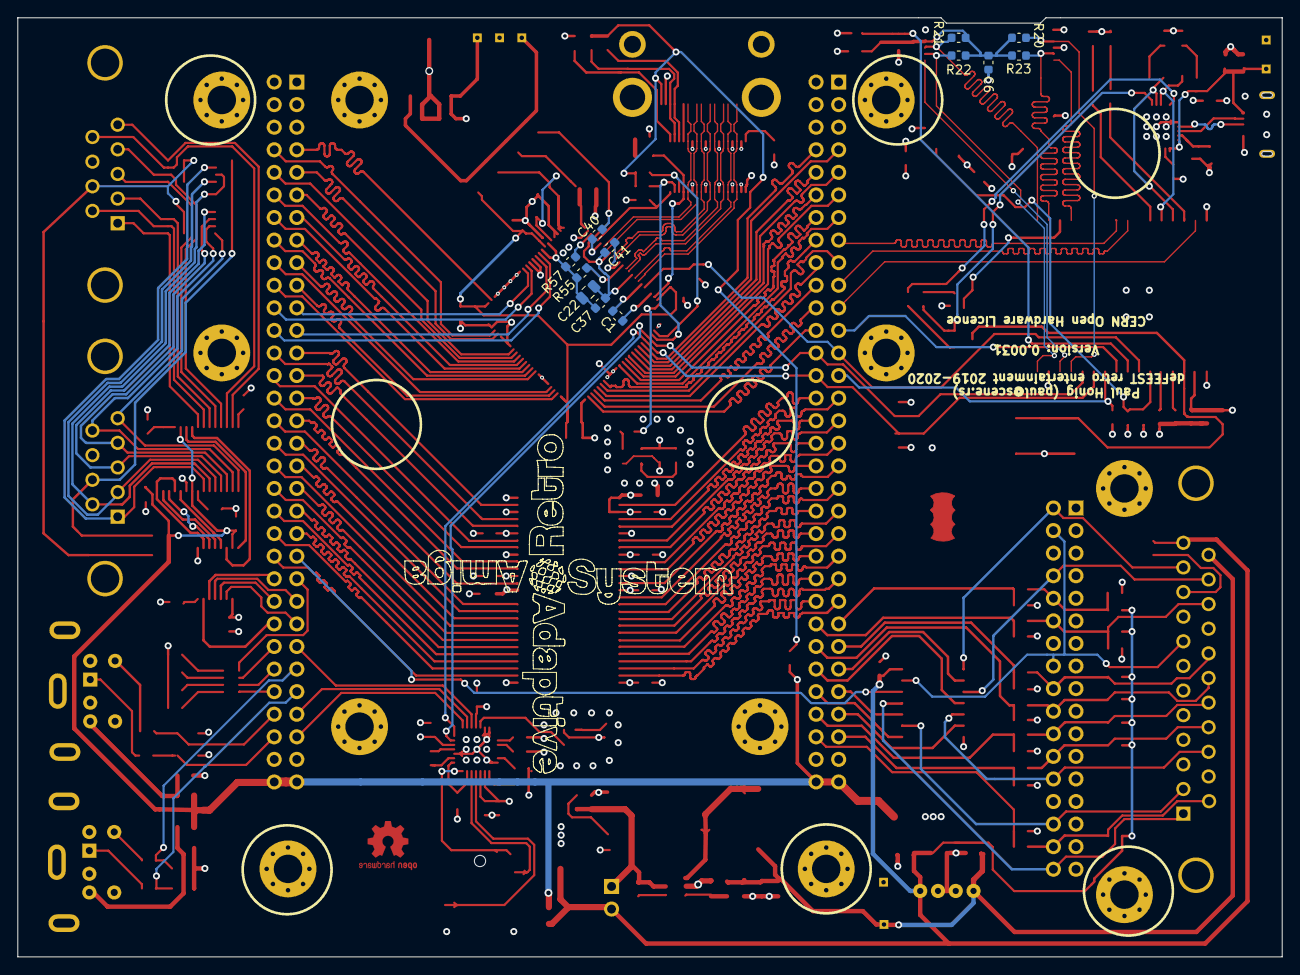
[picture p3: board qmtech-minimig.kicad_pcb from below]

Board: 4 copper layers, 142.2 x 105.7 mm, 206 parts (12 on the bottom side), 239 nets.

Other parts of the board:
C43#2: 10nF; C_0603_1608Metric
RN5: 1K; R_Array_Convex_4x0603

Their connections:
3V3: C43#2.2; also elsewhere on the board
/Main Board/LED0: RN5.1; also elsewhere on the board
/Main Board/LED1: RN5.2; also elsewhere on the board
/Main Board/LED2: RN5.3; also elsewhere on the board
/Main Board/LED3: RN5.4; also elsewhere on the board
GND: C43#2.1; also elsewhere on the board
unnamed 169: RN5.5; also elsewhere on the board
unnamed 170: RN5.6; also elsewhere on the board
unnamed 171: RN5.7; also elsewhere on the board
unnamed 172: RN5.8; also elsewhere on the board

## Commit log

2019-09-02 First checkin of work in progress minimig PCB.
    [MCU.sch, Video.sch, audio.sch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]
2019-09-02 Wired the RTL8211EG more.
    [MCU.sch, audio.sch, ethernet.sch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]
2019-09-03 Fixed wiring ad7511 and wired the rtl8211EG IC
    [MCU.sch, ethernet.sch, hdmi_transmitter.sch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]
2019-09-05 Moved to full size HDMI.
    [MCU.sch, audio.sch, ethernet.sch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]
2019-09-05 Added protection diodes to the joystick ports.
    [MCU.sch, hdmi_transmitter.sch, joystick.sch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]
2019-09-05 Added Control and audio lines to the ADV7511
    [main_board.sch, qmtech-minimig.kicad_pcb]
2019-09-05 Removed edge that should not have been there.
    [qmtech-minimig.kicad_pcb]
2019-09-07 Fixed connections for the adv7511. Fixed some minor footprint issues with the fpga board footprint.
    [MCU.sch, hdmi_transmitter.sch, main_board.sch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]
2019-09-08 Connected adv7511 unused inputs to ground. Added high voltage protection on PS2 port. Added indicators for the rubber glue on feet.
    [MCU.sch, audio.sch, ethernet.sch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]
2019-09-16 First step to implement floppy interface. ESP32 check wireing in.
    [MCU.sch, ethernet.sch, floppy.sch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]
2019-09-23 Integrated the Rover V2 into the board, added level shifters for the floppy interface.
    [MCU.sch, floppy.sch, main_board.sch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]
2019-09-24 Moved the micro USB connector to the bottom of the board, so the D+ and D- do not have to cross to the IC.
    [qmtech-minimig.kicad_pcb]
2019-10-06 Add the External floppy interface. Routed the HDMI tracks + match impendence.
    [MCU.sch, audio.sch, floppy.sch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]
2019-10-11 Fixed HDMI Impedance to 50Ohm, 100Ohm differential, for 0.1mm bord. Add pullups to HDMI I2C, connected DE pin to FPGA.
    [MCU.sch, floppy.sch, hdmi_transmitter.sch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]
2019-10-13 Fixed some issues with the 50 Ohm impedance of the SPI lines. Added pinout .odt.
    [MCU.sch, esp32-pinout.ods, hdmi_transmitter.sch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]
2019-10-13 Removed an extra esp32 footprint that was outside of the design.
    [keyboard.sch, qmtech-minimig.kicad_pcb]
2019-10-14 Add the missing files.
    [qmtech-minimig.kicad_pcb]
2019-10-24 Added ESD protection, and removed the curved lines around the adv7511.
    [MCU.sch, floppy.sch, hdmi_transmitter.sch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]
2019-10-29 Add an oscillator for the CEC functionality.
    [hdmi_transmitter.sch, joystick.sch, main_board.sch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]
2019-10-31 Added mounting holes.
    [hdmi_transmitter.sch, qmtech-minimig.kicad_pcb]
2019-12-03 Renamed some values for consistency
    [qmtech-minimig.kicad_pcb]
2019-12-05 Changed zener diode footprint for easy soldering. Fixed pins, U861/2 and U761/2 they now connect correctly to ground.
    [MCU.sch, audio.sch, floppy.sch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]
2019-12-24 Fixed reversed labeling of the QMTECH FPGA board pins.
    [MCU.sch, hdmi_transmitter.sch, main_board.sch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]
2020-01-12 Add Max9850 to handle audio.
    [audio.sch, floppy.sch, main_board.sch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]
2020-01-12 Joystick port 7 is not powered at 5V, polyfuses have been added, txs0108 are used for the joystick ports.
    [audio.sch, joystick.sch, keyboard.sch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]
2020-01-12 The DB9 connectors now have ground on the outer sleve.
    [joystick.sch, qmtech-minimig.kicad_pcb]
2020-01-18 Change order of the VSPI to FPGA to make sure the clock pin connects to an FPGA clock capable pin.
    [MCU.sch, audio.sch, floppy.sch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]
2020-02-23 Add PS/2 Mouse connector to the board, USB has too much overhead.
    [MCU.sch, keyboard.sch, main_board.sch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]
2020-03-08 Add 3d models to most components, Add decoupling of the Line ins of the max9850. Add new defeest Logos.
    [audio.sch, esp32-pinout.ods, hdmi_transmitter.sch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]
2020-07-13 Minimig V2
    [MCU.sch, pinout-open-aars.ods, qmtech-minimig.kicad_pcb]
2020-07-13 First checkin of SDRAM Open AARS board.
    [MCU.sch, audio.sch, floppy.sch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]
2020-07-13 Fixed some weird routing.
    [qmtech-minimig.kicad_pcb]
2020-07-16 Implemented the Floppy interface, fixed 12V power up issue with the board.
    [audio.sch, floppy.sch, joystick.sch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]
2020-07-16 Version that was sent to JLCPCB 20200716.
    [floppy.sch, joystick.sch, main_board.sch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]
2020-07-18 Fixed SDRAM_A12 missing route, disconnected JS_INT_B.
    [main_board.sch, pinout-open-aars.ods, qmtech-minimig.kicad_pcb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]
2020-07-27 Fixed I2C pullup resistors.
    [hdmi_transmitter.sch, joystick.sch, main_board.sch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]
2020-09-27 Add footprints in Library. Add picture of the finished board in README.
    [pinout-open-aars.ods, qmtech-minimig.kicad_pcb]
2020-09-29 Fixed regression from an earlier pin numbering mistake. Changed Joystick pullups for resistor network.
    [joystick.sch, main_board.sch, qmtech-minimig.kicad_pcb]
2020-09-30 Fixed some external dependencies.
    [MCU.sch, audio.sch, floppy.sch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]
2020-09-30 Update README with disclaimer.
    [qmtech-minimig.kicad_pcb]
2020-09-30 Revert "Fixed some external dependencies."
    This reverts commit ddca1efdf68af69ddd54947bcdaa3cfa1d913e0d.
    [MCU.sch, audio.sch, floppy.sch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]
2020-09-30 Fixed Missing PCB logos.
    [qmtech-minimig.kicad_pcb]
2020-10-01 Fix missing resistor array.
    [main_board.sch]
2020-10-06 Removed all libraries that depend on absolute paths.
    [MCU.sch, audio.sch, floppy.sch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]

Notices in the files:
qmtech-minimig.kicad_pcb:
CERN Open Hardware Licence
